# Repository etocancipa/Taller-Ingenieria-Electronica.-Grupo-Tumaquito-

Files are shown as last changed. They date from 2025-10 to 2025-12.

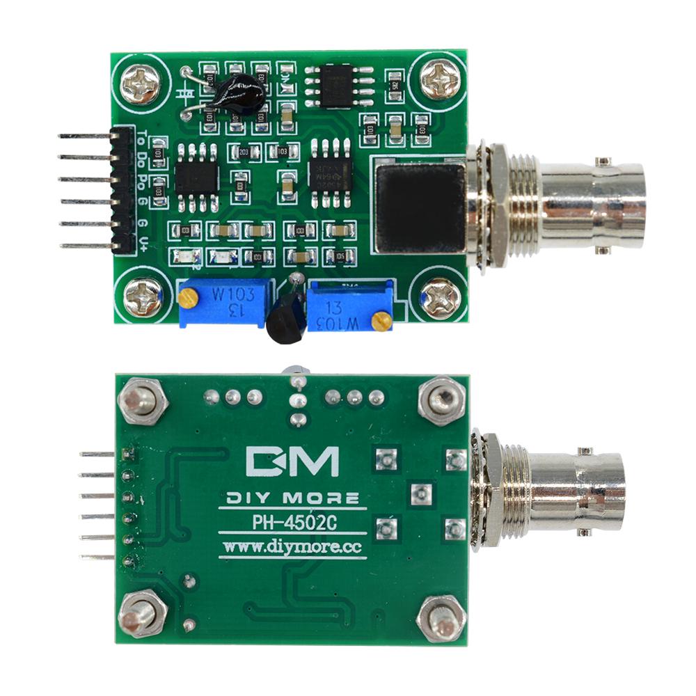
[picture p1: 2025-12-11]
PCB Tumaquito/Librerias/step/ph-4502c-1.snapshot.5/PH-4502C.jpeg

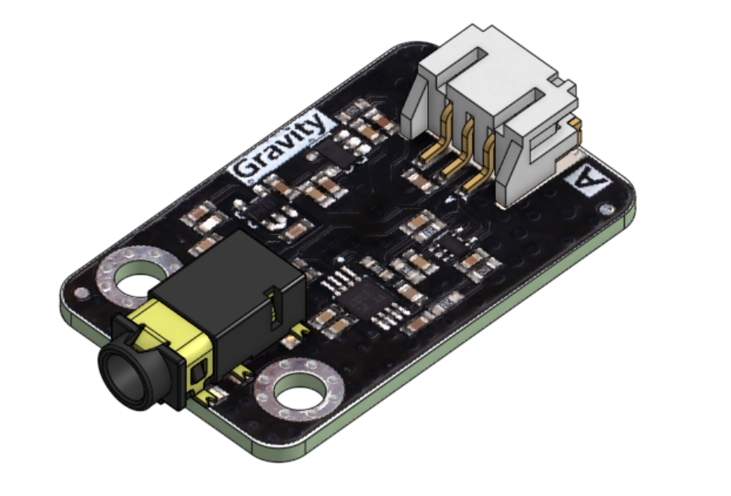
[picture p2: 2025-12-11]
PCB Tumaquito/Librerias/step/dfrobot-gravity-analog-emg-sensor-by-oymotion-sen0240-1.snapshot.2/emg_sensor.png

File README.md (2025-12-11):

# Taller-Ingenieria-Electronica.-Grupo-Tumaquito-
Este sera el repositorio del grupo "Tumaquito". Aqui se registraran la documentación y avances en el proyecto.

## LEER WIKI PARA DETALLES DEL PROYECTO

## Integrantes:
+Joseph Reyes

+Jose Dario

+Luis Cortes

+Eddy Tocancipa

+Helen Hernandez

+Sebastian Vanegas

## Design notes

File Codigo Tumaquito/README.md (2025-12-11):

# CODIGO APLICACIÓN Y ESP32:

El proyecto cuenta con una configuración para la ESP32 que pueda leer las señales analogicas.

Ademas de este codigo se cuenta con una aplicación hecha en APPINVENTOR, con su respectivo codigo en bloques.

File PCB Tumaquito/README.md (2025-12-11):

# ARCHIVOS PCB TUMAQUITO:

Aqui puedes encontrar la totalidad de los archivos que fueron utilizados para la creción de la PCB de Tumaquito!

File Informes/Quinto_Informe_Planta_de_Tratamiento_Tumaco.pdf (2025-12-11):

# Quinto Informe Planta de Tratamiento Tumaco

Luis Cortes
Helen Hernandez
Sebastian Vanegas
Eddy Tocancipa
Jose Dario
Joseph Reyes

Noviembre 2025

## 1. Introducción:

Durante esta quinta semana se arreglo la aplicación desarrollada para el proyecto, siendo ahora compatible con internet y funcional al conectarse con el servidor de la ESP32.
También se termino la PCB requerida para el proyecto, pero esta requerirá múltiples cambios recomendados por el profesor de Taller ademas de unos ajustes, se especificara en la sección del informe destinada a la PCB.
Se inició con el desarrollo de la caja del proyecto donde se instalaran los sensores, PCB y probeta requerida para las muestras.
El equipo tuvo un punto de flexión durante esta semana, esto se descubrió durante la exposición del miércoles y revoluciono nuestra perspectiva y forma de trabajo, se dedicara un apartado especial dentro del informe a nuestra nueva metodología de trabajo.

1

## 2. Aplicacíon Tumaquito:

La interfaz sigue siendo la misma, este es el ultimo punto a cambiar, lo que seria decorarla y añadirle estilo.
La aplicación en si es funcional, ya se conecta al servidor WIFI de la ESP32 y reconoce los valores analógicos que este manda. Se dejara este apartado en espera hasta que el dispositivo este armado, se harán las pruebas en aquel momento.

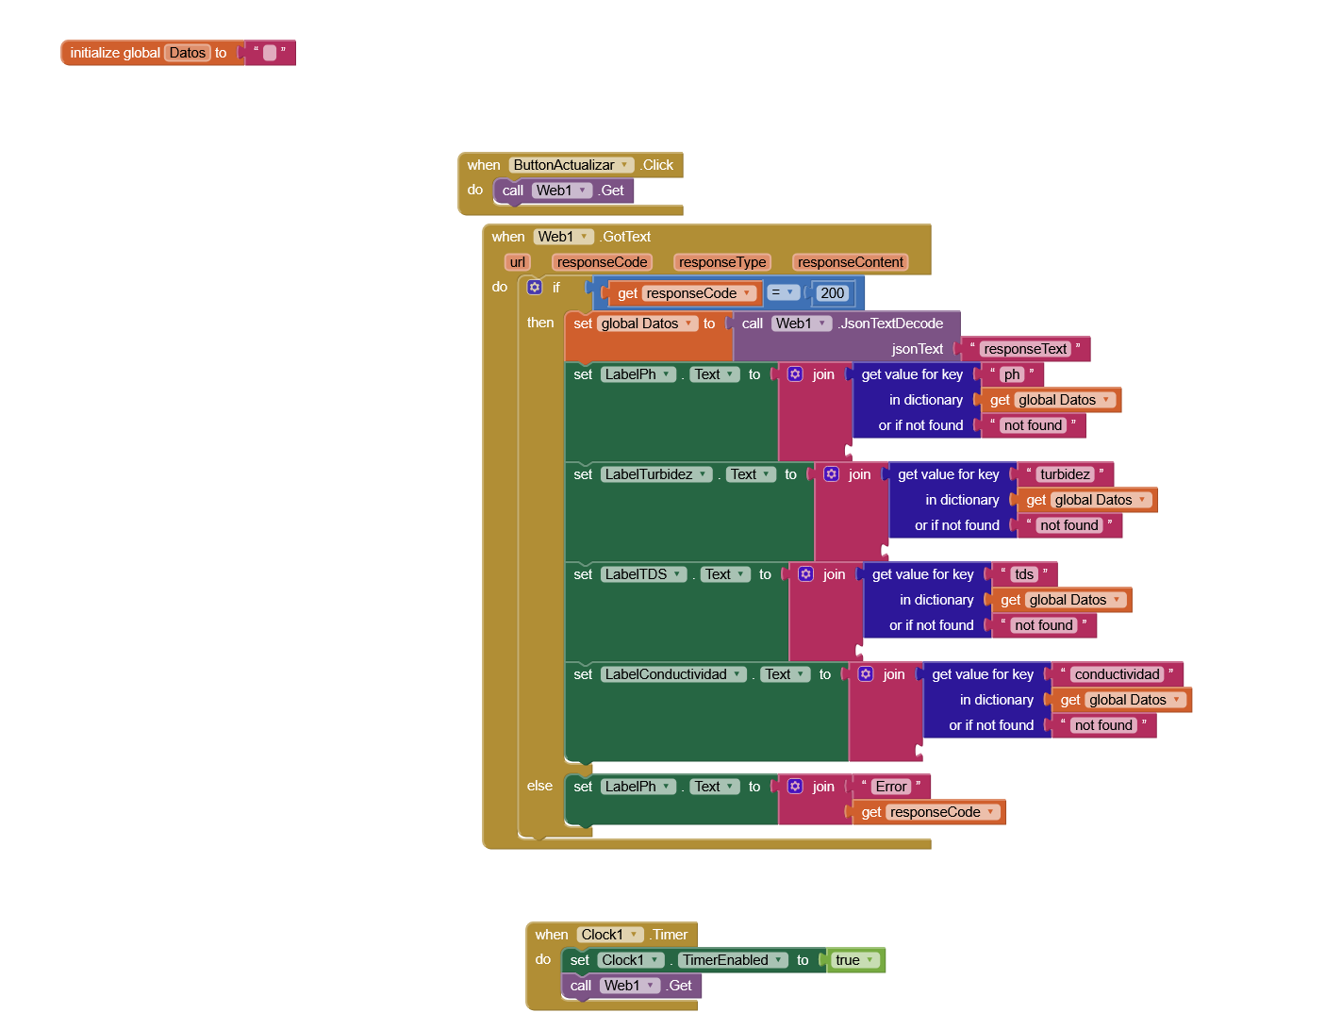
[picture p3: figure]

Figura 1: Nuevo codigo adaptado al servidor WIFI de la ESP32

## 3. Programación servidor ESP32:

Nos encontramos con un problema al configurar el código de los 3 sensores y subirlo al servidor ya que los valores enviados superan una capacidad máxima dada por el ESP32. Esto al probar el servidor con los sensores por separado no sucedía por la menor cantidad de datos que se recibían. Nos pusimos en contacto con unos estudiantes de programación que apoyan en Tutorías con Ingenio para saber si nos ayudaban a solucionar este problema o reconocer como tratarlo.

2

## 4. PCB:

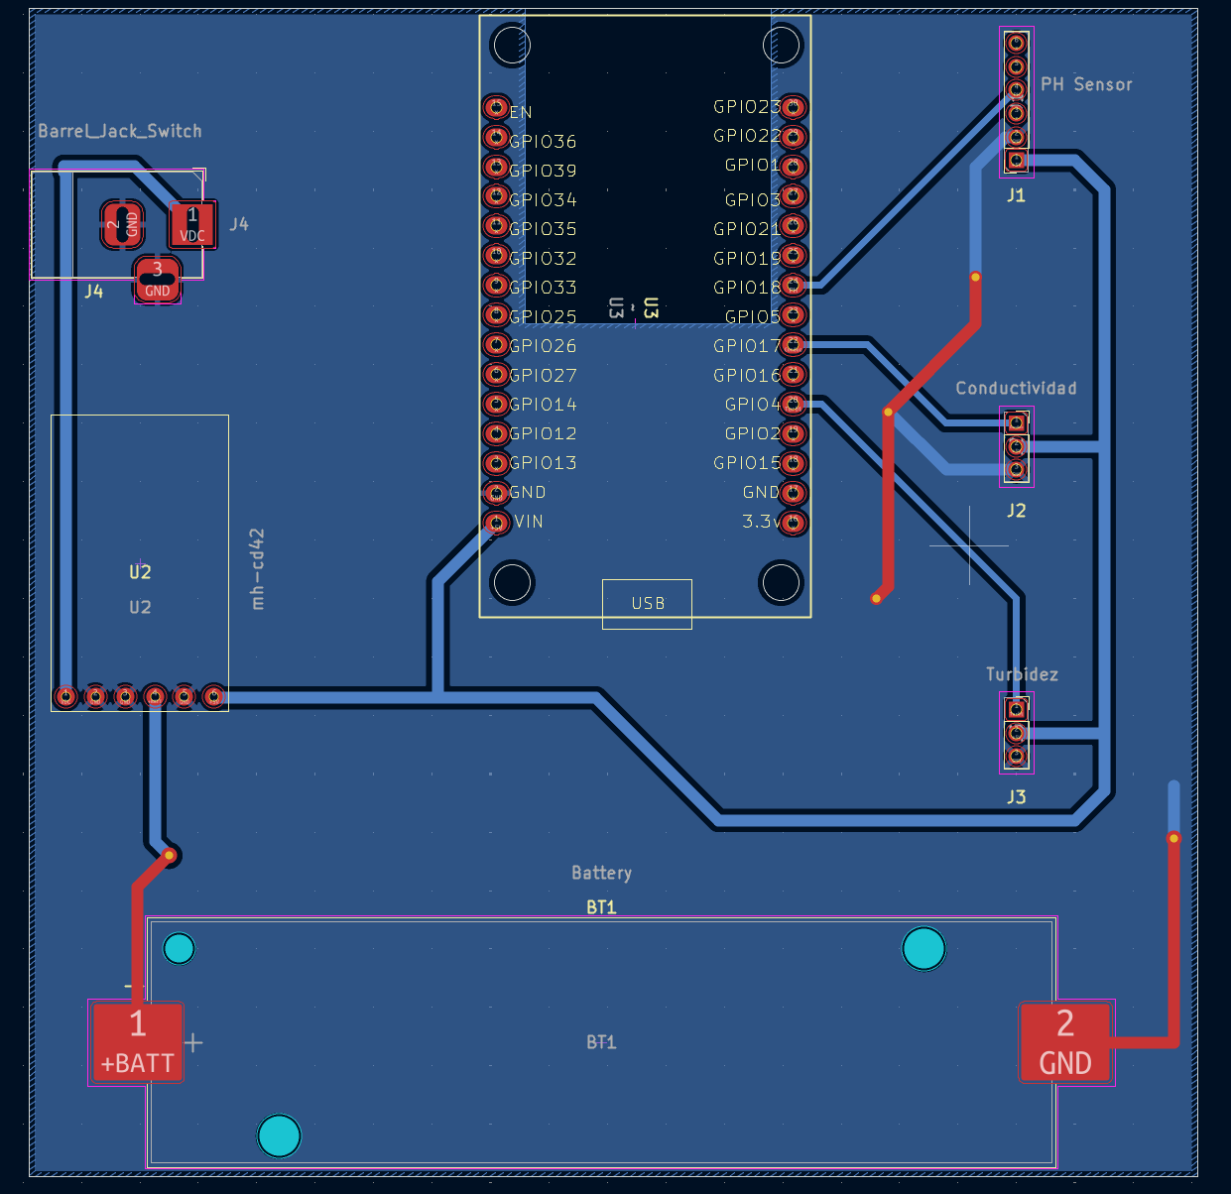
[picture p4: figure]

Figura 2: Version 1.

La imagen de arriba presenta la PCB que fue presentada al profesor de Taller, este hizo numerosos apuntes que se enumeraran a continuación:

### 1. Los sensores (Conectores de la derecha) Deben ser movidos a la izquierda

de la PCB para utilizar los Pines del bloque 1, ya que los pines a los que se conectaron tienen interferencias al usar el modulo WIFI de la ESP32.

### 2. Los sensores de conductividad y turbidez deben ser movidos a la entrada de

energía 3.3V ya que aunque funcionan en la entrada VIN se genera un campo eléctrico que puede causar interferencias entre ellos.

### 3. Este cambio fue descubierto por nosotros al probar el sensor de PH en el

ESP32 en vez del arduino, y es que este al dar señales analógicas de 5v no son captadas por el ESP32, se le comento al profesor de taller y nos dijo que implementáramos un divisor de voltaje en la PCB con un potenciómetro para bajar la señal de 5v a 3.3v o 3v.

### 4 Hubo ajustes pequeños como el tamaño de las vías o el margen que tienen

estas con la base GND.
Ya estamos realizando estos cambios necesarios para poder enviar a imprimir la PCB, se comunicara con el profesor de Taller de forma virtual para avisar si los cambios hechos fueron realizados de manera correcta.

3

## 5. Caja del Proyecto:

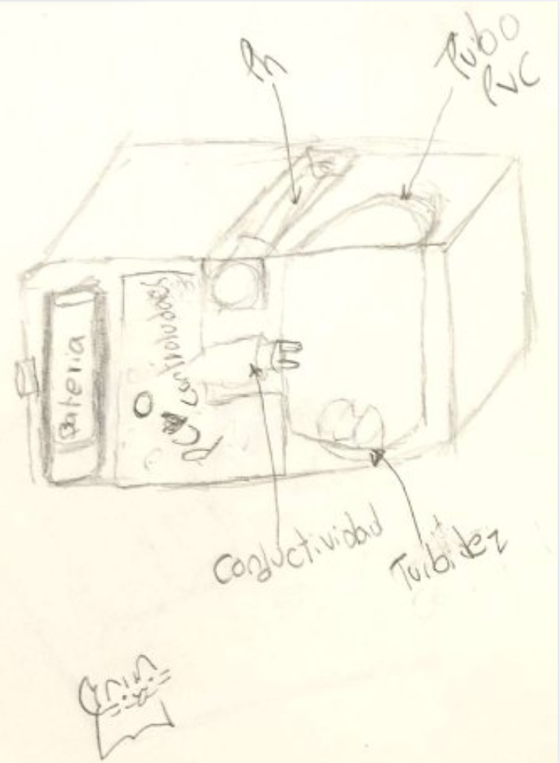
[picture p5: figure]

Figura 3: Bosquejo Caja del proyecto.

Seguimos en un bosquejo (Se programo reunir el viernes para definir al completo la caja).
Tenemos conceptos claros como el tubo de PBC dividido para cada sensor, el sistema de energía utilizando un jack y la forma en general que tomara la caja ”Tumaquito”. Se piensan definir materiales, dimensiones y cronograma para ensamblaje y pruebas.

## 6. Nueva metodología:

Hasta el momento el equipo había cumplido con las tareas asignadas a cada integrante, cada uno trabajo como lo esperado y se realizaban pequeñas reuniones para acordar actividades o cuadrar exposiciones.
Aun así fuimos expuestos a un problema durante la ultima exposición que nos dio a conocer nuestra mayor inconveniente y es que en realidad estábamos trabajando de forma individual, de forma que cada uno tenia una idea general pero distorsionada del proyecto, se generaban contradicciones y confusiones en ciertas áreas de trabajo.
Este individualismo se genero por una falta de presencia en el trabajo grupal, cada uno tenia su propia actividad y no se preocupaban por la de otro o por una perspectiva mas ”General”. No se acordaba una actividad que se desarrollara

4

con el grupo entero de forma presencial.
Tuvimos esta conclusión y nos dimos cuenta que no dábamos la imagen de ’Equipo’. Para contrarrestarlo decidimos desarrollar el resto del proyecto de forma presencial, de manera continua y casi diaria evitando en la medida de lo posible destinar tareas y procesos de forma individual.
NOTA EDDY: Cada uno estuvo de acuerdo y de hecho fueron 4 integrantes los que propusieron esta metodología, nos pusimos de acuerdo en que íbamos a trabajar de manera presencial y dedicarle nuestro tiempo y espacio a el apartado de ensamblaje y construcción de lo que queda del proyecto.

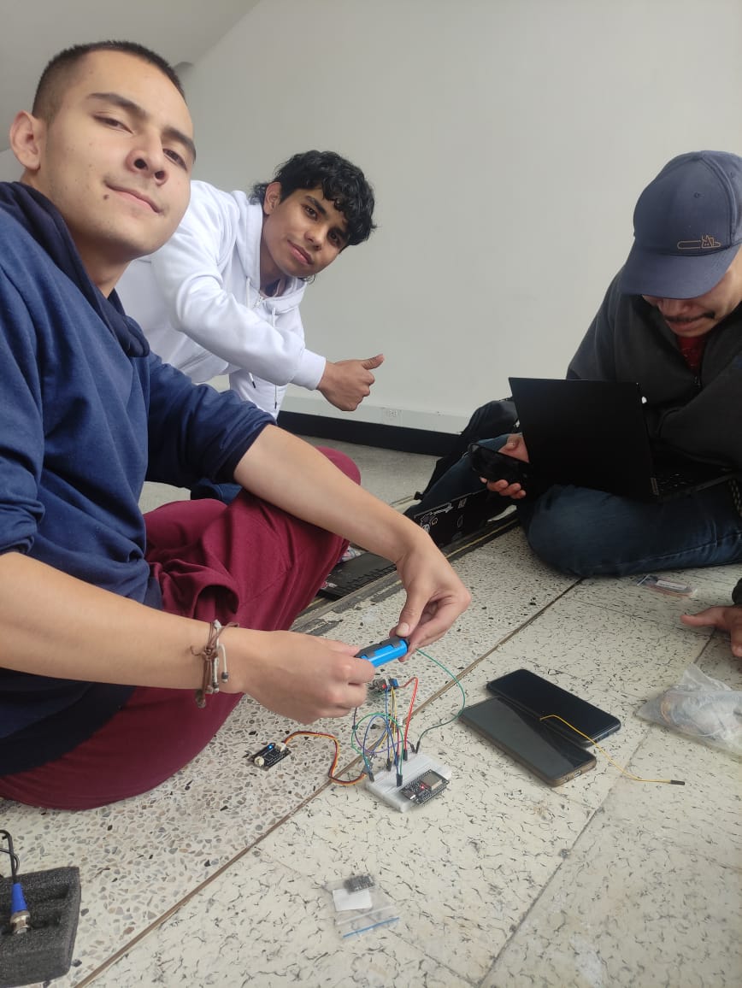
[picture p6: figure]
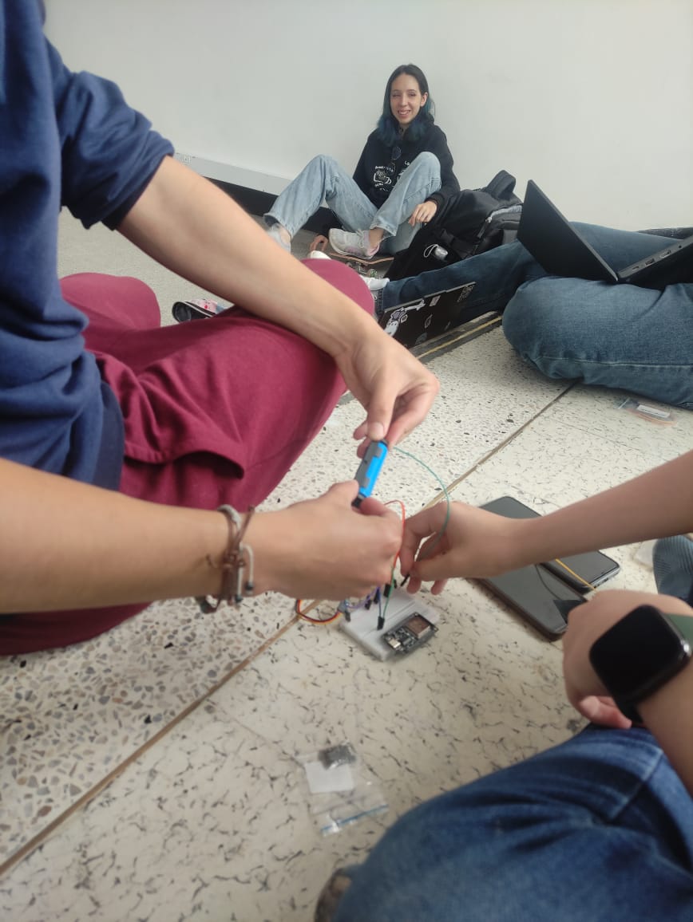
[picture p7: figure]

5

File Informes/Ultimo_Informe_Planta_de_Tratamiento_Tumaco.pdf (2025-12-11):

# Ultimo Informe Planta de Tratamiento Tumaco

Luis Cortes
Helen Hernandez
Sebastian Vanegas
Eddy Tocancipa
Jose Dario
Joseph Reyes

Diciembre 2025

## 1. Introducción

Estas ultimas 2 semanas hemos trabajado en todo el aspecto técnico y cacharrero.
Trajimos a la vida ”Tumaquito”. Logramos imprimir la PCB, Soldar los componentes y tener parte la caja lista. En términos generales solo quedaría montarlo todo en un solo dispositivo y solucionar varios errores que hemos tenido. Iremos paso a paso.

## 2. PCB

Tuvimos el visto bueno del profesor de taller. Este vio nuestro diseño, nos aconsejo unos cambios menores y después de arreglarlos la mandamos a imprimir.
Una vez imprimida notamos solo 2 temas, los agujeros para el jack eran muy chiquitos y no cabía por completo el porta-pilas, afortunadamente estos problemas se solucionan de forma sencilla reduciendo el tamaño de los pines del jack y un poco de ayuda para soldar el porta-pilas, esto para que tenga el roce necesario con el cobre.

1

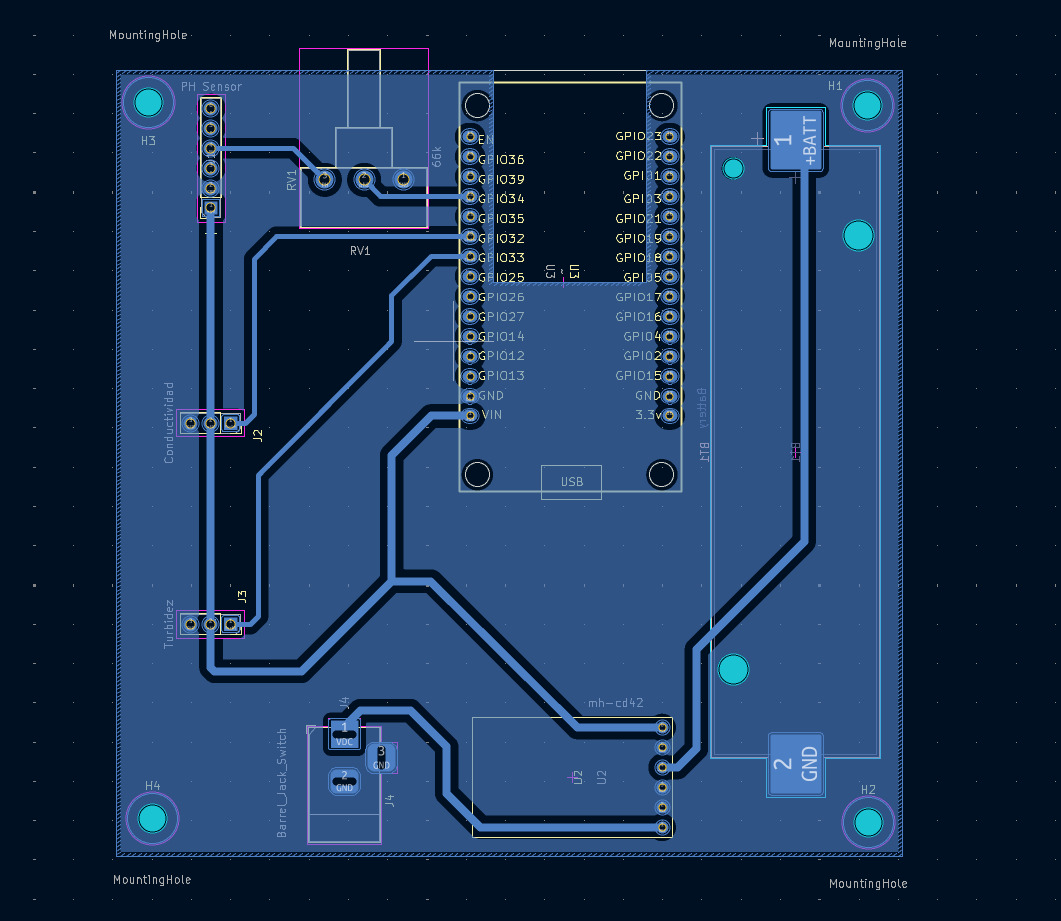
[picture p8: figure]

Figura 1: Diseño final de PCB

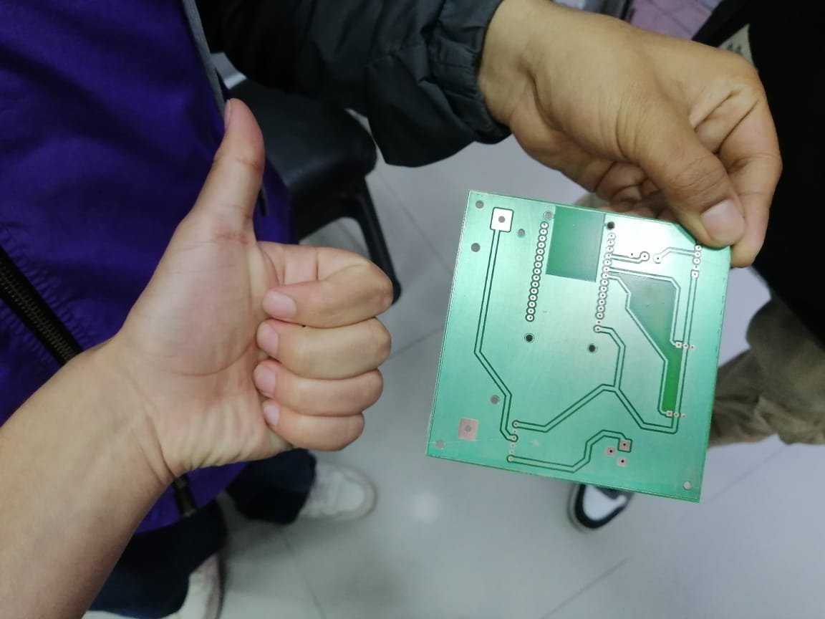
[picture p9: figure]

Figura 2: Recogiendo la PCB

2

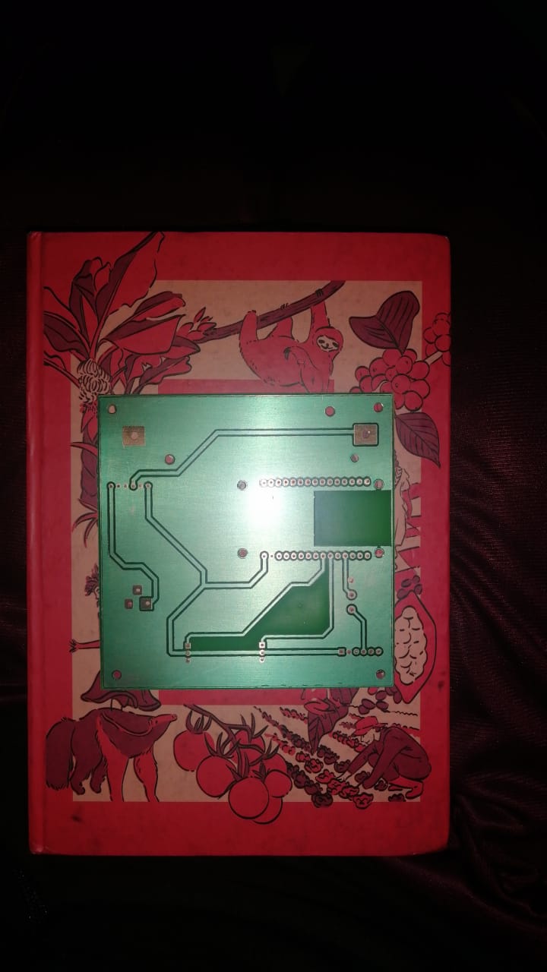
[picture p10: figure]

Figura 3: PCB por detrás. Circuito.

3

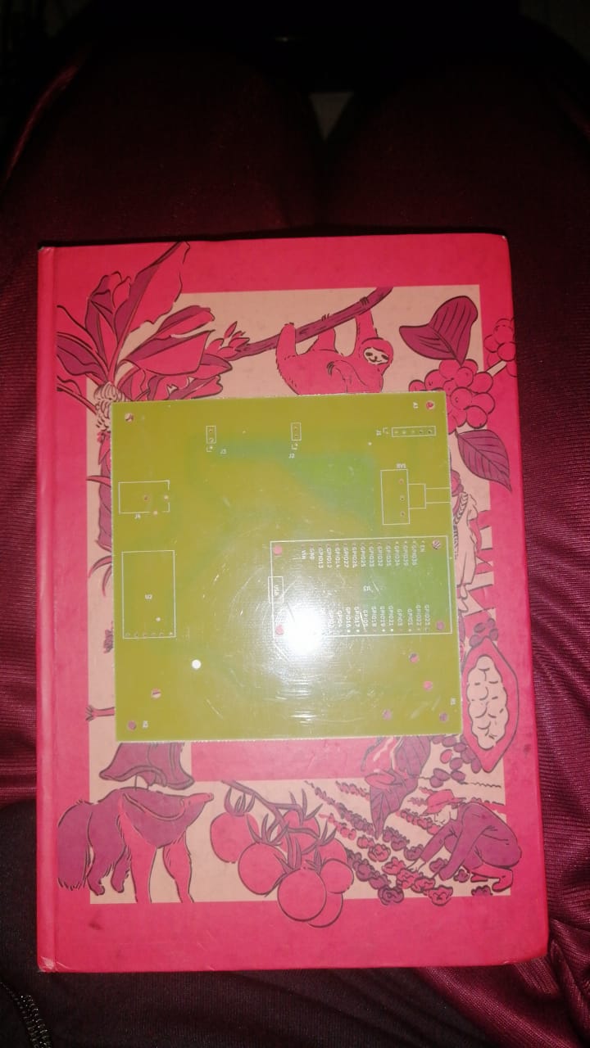
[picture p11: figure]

Figura 4: PCB por delante. Componentes.

## 3. Soldadura

Era nuestra primera vez para la mayoría del equipo, por lo que al momento de soldar tuvimos varias dificultades.
Cada uno quería practicar y mejorar su soldadura por lo que nos dividimos los componentes, Soldamos por 3 días turnándonos la PCB y revisando continuamente que nos fuera quedando de manera adecuada.
No fuimos muy limpios con el cautín por lo que al final su punta se lleno de corrosión y dejo de calentar como es debido.
Utilizamos flux demás, esto causo que la PCB Queda pegachenta al tener un montón de liquido derramado, tardamos un tiempo en limpiarla porque teníamos miedo del alcohol normal y que dañara la PCB.
Varios metimos mas estaño del que debíamos, quedando con pines muy robustos, a fecha de la escritura de este informe tenemos problemas con la conductividad de energía de algunos componentes, quizá por mala soldadura.

4

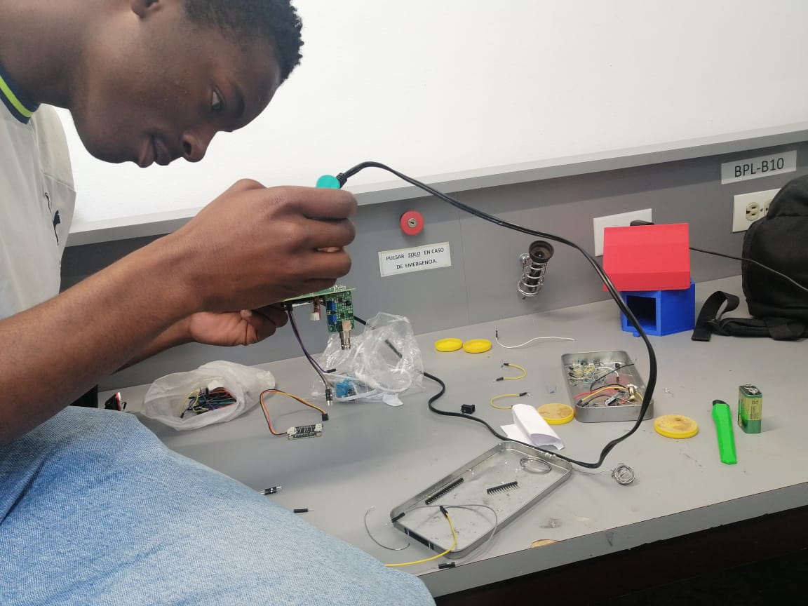
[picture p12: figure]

Figura 5: Soldando

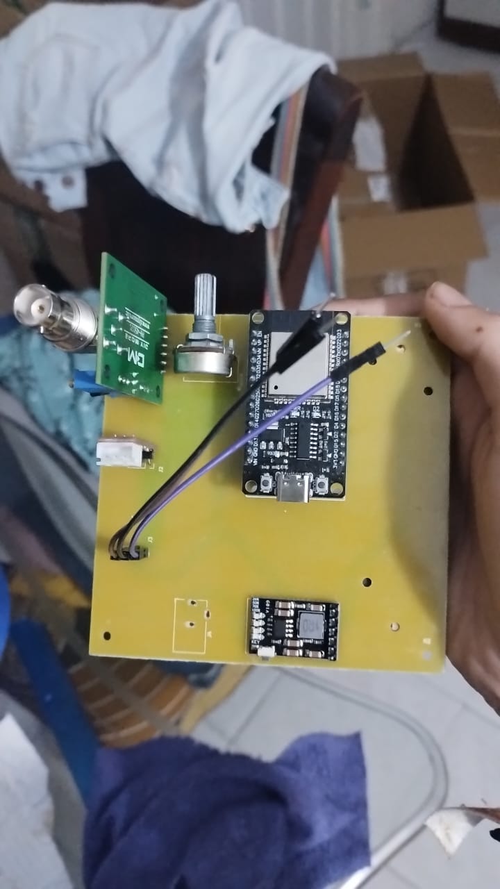
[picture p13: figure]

Figura 6: Soldadura Delantera PCB

5

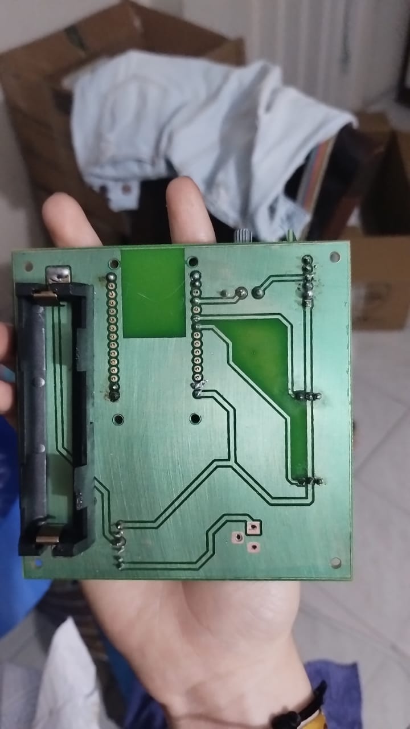
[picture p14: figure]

Figura 7: Soldadura Trasera PCB

## 4. Caja Tumaquito

Con las mediciones de la PCB, un tubo de muestra y el espacio a ocupar por los sensores, pudimos adelantar un diseño hecho en tinkercard que después imprimimos a 3D, dándonos nuestro primer esquema de caja y donde planeamos instalar todos los componentes.
Al principio pensamos en una caja, pero después de varias charlas dijimos que era muy feo. Optamos por un un cilindro.

6

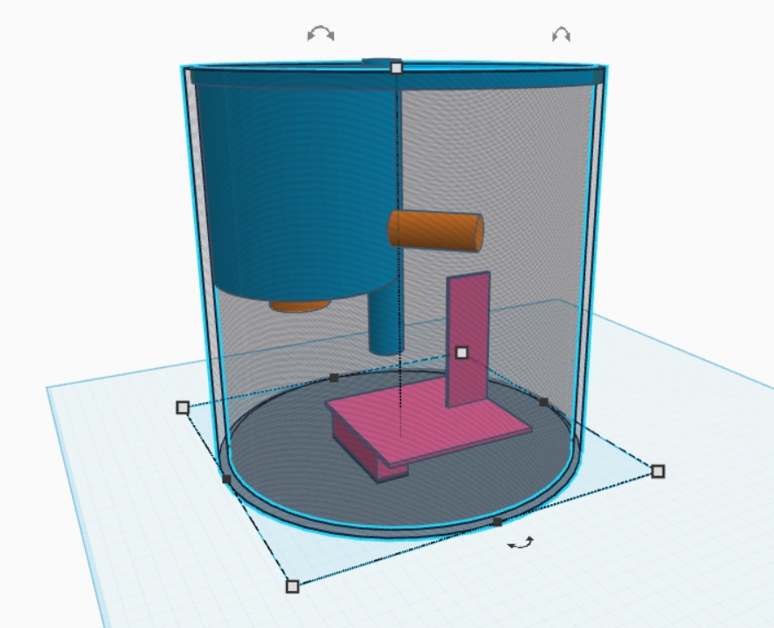
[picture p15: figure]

Figura 8: Boceto Caja tinkercard

Después de este boceto nos enteramos que la sonda de PH seria un problema para el proceso de mantenimiento por lo que decidimos que esta se pueda sacar de la caja e interactuar de manera manual por el usuario para medir la muestra.

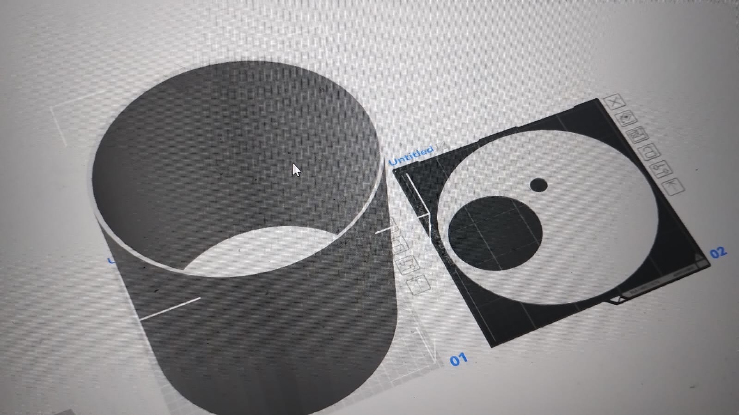
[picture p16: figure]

Figura 9: Diseño Final Caja

Ya con este diseño se empezó la impresión 3D.

7

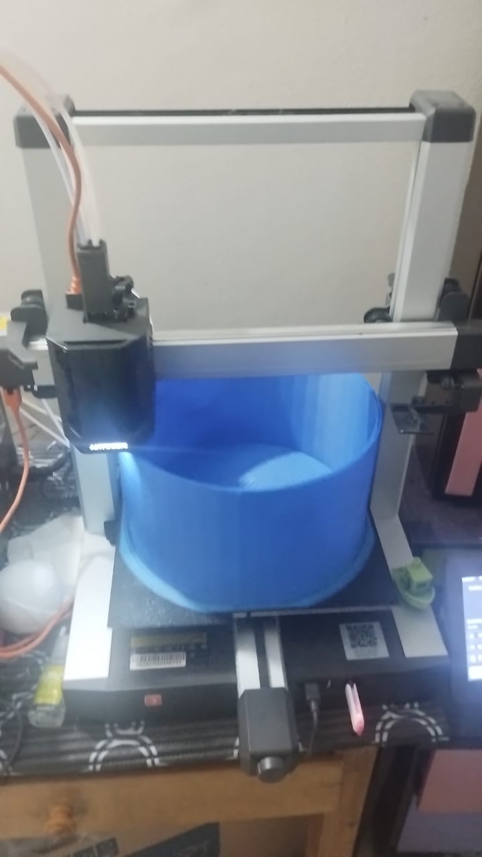
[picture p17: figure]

Figura 10: Impresión Caja 3D

En ultimas los problemas al montar todo en la caja vendrán durante estos últimos días de trabajo ya que es la parte final para poder entregar a Tumaquito. Se tiene el espacio para cada componente, lo necesario sera realizar los huecos tanto para el jack como para la calibración del sensor de PH.

## 5. Aplicación

La aplicación se encuentra funcional. Varios miembros dedicaron tiempo en mejorar su interfaz y añadir funciones.
Ahora la aplicación puede dar un ”Tratamiento”que busque (según el estado del agua y sus parámetros medidos) aconsejar al usuario en un método de acción que ayude a purificar el agua, haciendo posible su uso.
Aun faltan pruebas con soluciones y muestras para saber si esta nueva función se encuentra en buen estado, pero debido a problemas con la conductividad en la PCB se han aplazado estas pruebas.

8

## 6. Problemas:

### 1. Dañamos la sonda de PH. Esto por conectarla directa sin bajar el voltaje de

su pin analógico. Dimos vueltas por la 19 buscando que nos vendan unicamente la sonda pero no tuvimos suerte, al final la ordenamos por internet.

### 2. Hay un ’salto’ en la lectura de datos de los sensores debido a que todos están

al mismo pin de la ESP32, este margen de error se puede manejar por medio de programación.

### 3. No sabemos bien, de pronto por soldar mal o por realizar pruebas con pines en

corto, pero algunos componentes como el controlador de turbidez y el cargador de baterías cd-42 no conducen la energía la PCB lo que genera que no se lean sus datos o que por medio de una pila no se pueda encender todo el circuito. Esperamos obtener ayuda por parte de los profesores de taller en caso de que nuestros esfuerzos por solucionar estos problemas se vean en vano.

## 7. Terminación

Nuestros últimos pasos para el proyecto serian solucionar el tema de la PCB para que funcione y los sensores lean los datos alimentados por una pila, ademas de instalar todos los componentes en la caja y decorarla. Muchas gracias.

FIN DEL INFORME

9

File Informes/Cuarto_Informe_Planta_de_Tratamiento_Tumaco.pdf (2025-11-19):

# Cuarto Informe Planta de Tratamiento Tumaco

Luis Cortes
Helen Hernandez
Sebastian Vanegas
Eddy Tocancipa
Jose Dario
Joseph Reyes

Noviembre 2025

## 1. Introducción

Esta cuarta semana se trabajo en el circuito de los componentes del proyecto, así terminando una versión pendiente de la revisión del profesor de taller y que a la vez pueda trabajarse en la creación de la PCB, la cual sera objetivo para la 5° semana.

Se trabajo con el APPINVENTOR, obteniendo una beta de la aplicación para celular que se usara en la sincronización de datos con la ESP32. Se mostraran componentes de la interfaz que reflejan como se verán los datos en pantalla recibidos de las muestra.

Aparte de estos 2 avances se hicieron mas pruebas con los sensores, realizando cambios en su programación, ajustes y adaptando el informe que el usuario use dentro de la aplicación.

1

## 2. Circuito Electrónico - Componentes

Utilizando Kicad, se siguió el tutorial hecho por el profesor Johnny Cubides que enseña lo básico para desenvolverse en la plataforma. Se idearon las conexiones, tierras y sistema de energía que alimente a los sensores.
Este es el esquema:

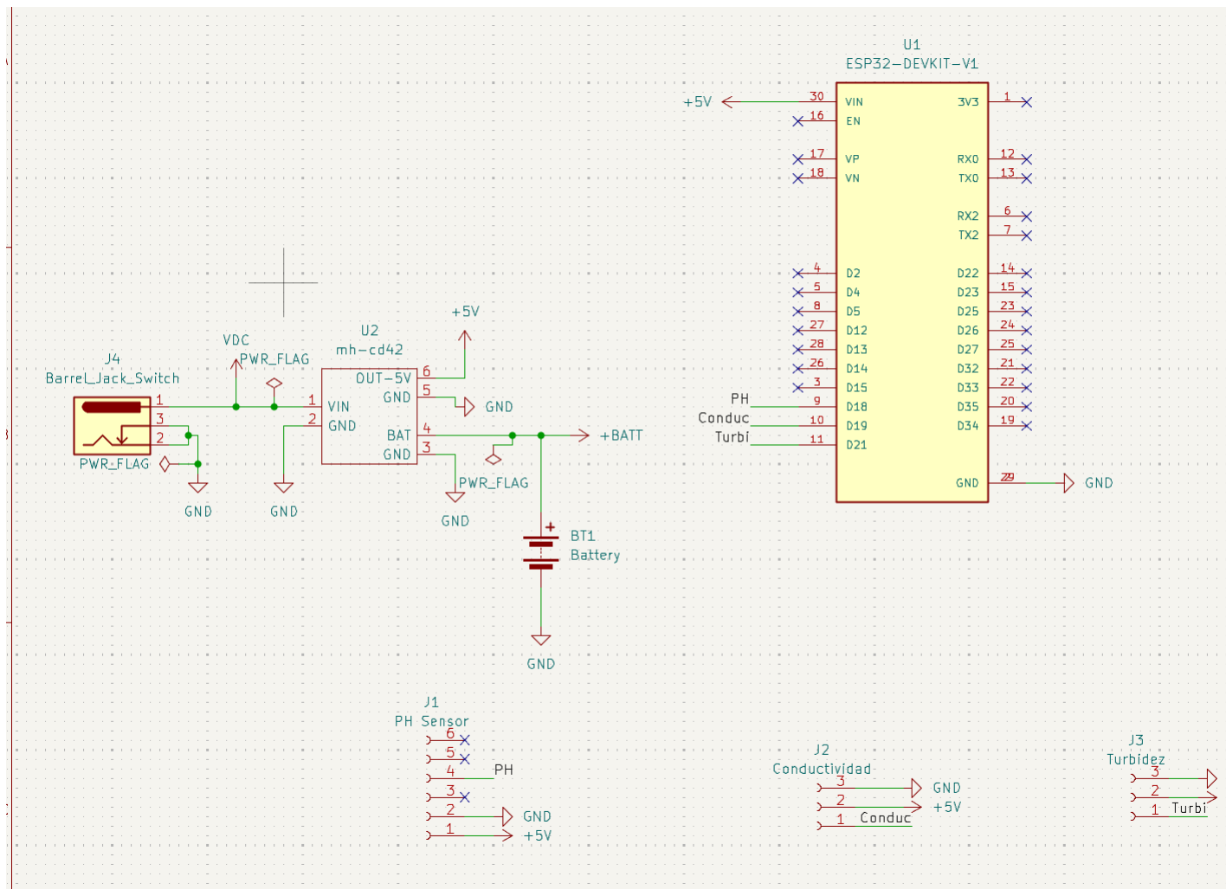
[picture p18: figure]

Figura 1: Circuito ideado en KICAD

Como resumen, los 3 componentes de la izquierda son la energía del sistema (Jack, Batería, Cargador de batería).
Los 3 componentes de abajo de la imagen son los sensores representados unicamente con sus conexiones (Hembra) Debido a que no existen símbolos y huellas de ellos para este programa.
El componente de la derecha - arriba es la ESP32 que, usando un diagrama de conexión del fabricador de donde conseguimos nuestra ESP32, nos pudimos

2

guiar en los pines a usar que facilitaran su acomodación durante la creación de la PCB.

## 3. Aplicación TUMAQUITO:

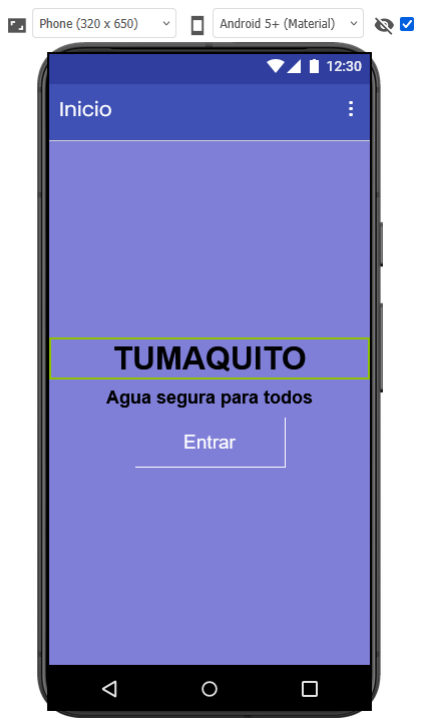
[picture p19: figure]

Figura 2: Pantalla 1

Figura 3: Programación Pantalla 1

3

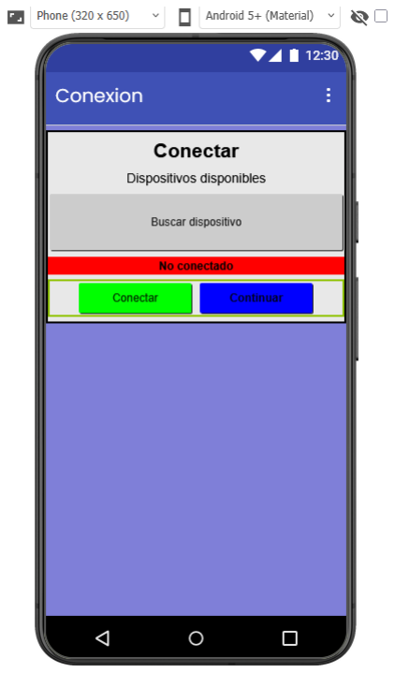
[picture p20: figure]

Figura 4: Pantalla 2

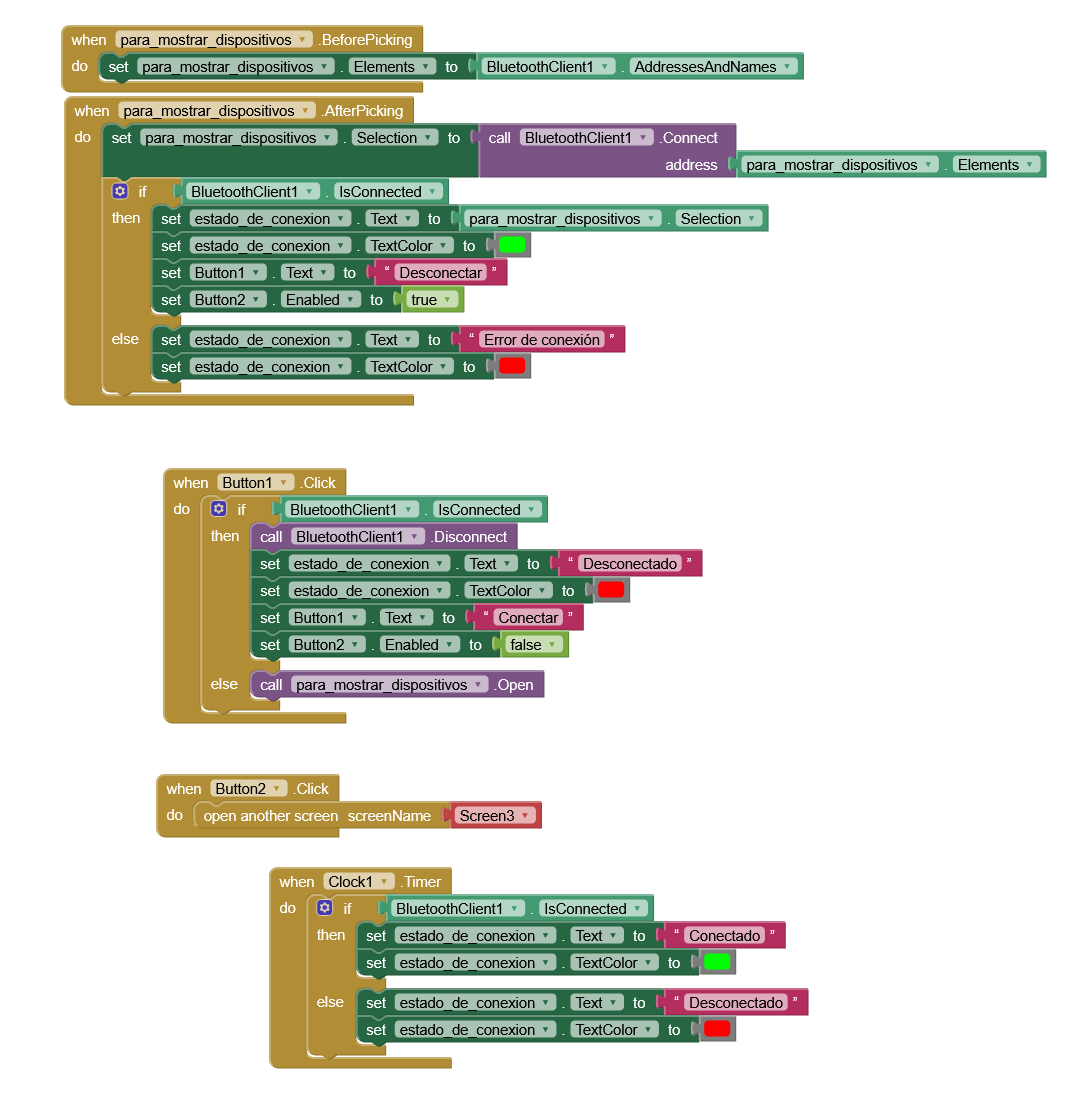
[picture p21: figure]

Figura 5: Programación Pantalla 2

4

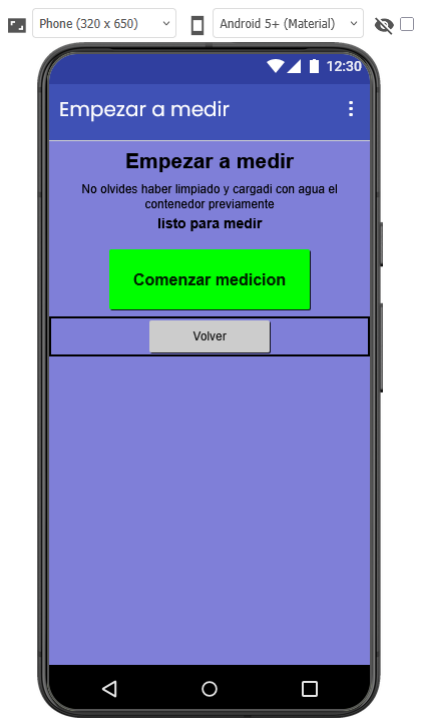
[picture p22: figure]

Figura 6: Pantalla 3

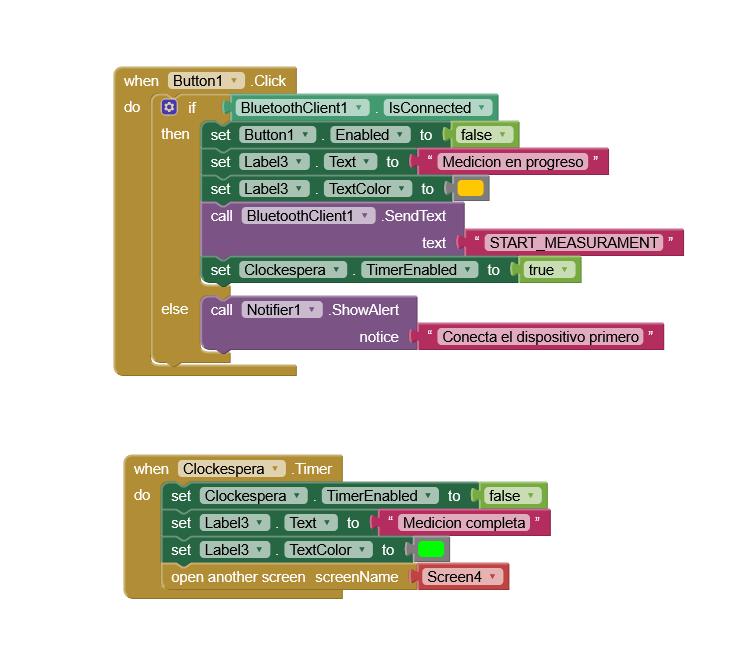
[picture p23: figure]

Figura 7: Programación Pantalla 3

5

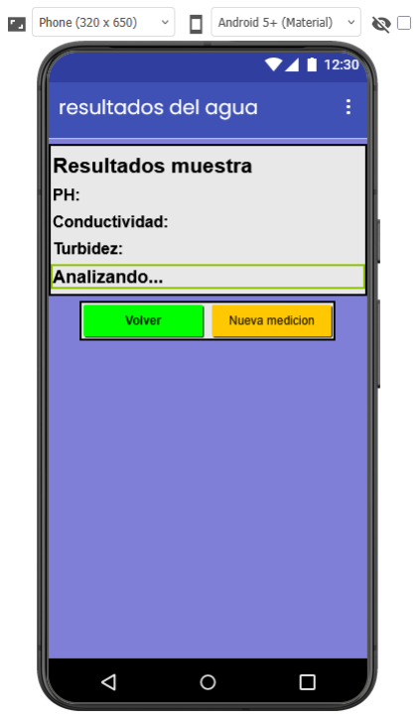
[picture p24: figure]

Figura 8: Pantalla 4

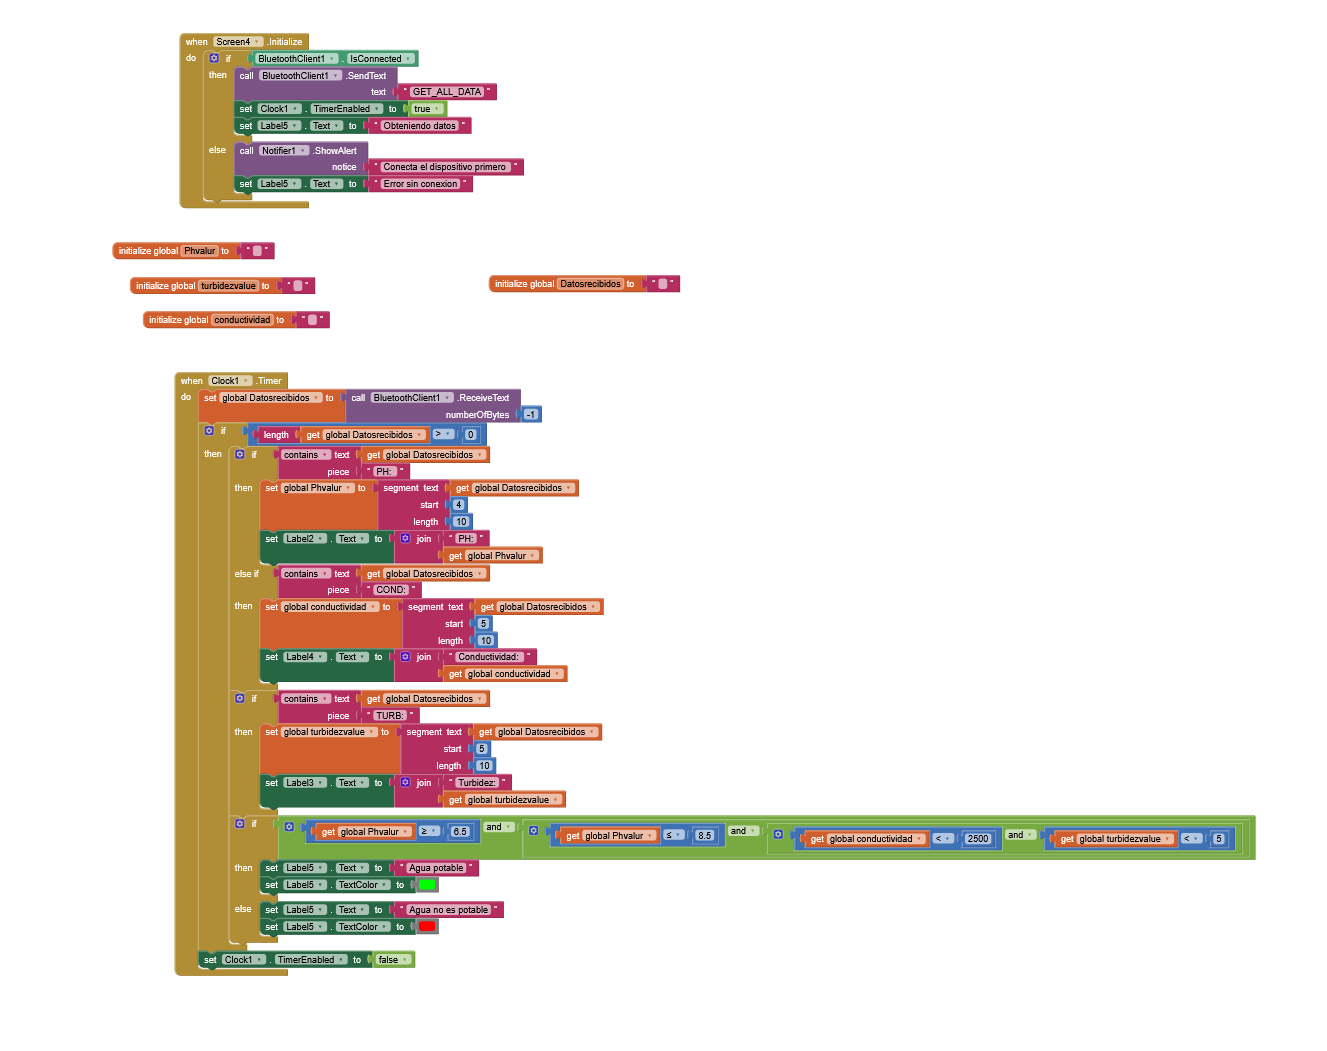
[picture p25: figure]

Figura 9: Programación Pantalla 4

Esta NO es la versión final. Es una ”Beta”funcional que da una idea de adonde se va dirigiendo la aplicación.
Debido a un problema de comunicación se configuro la aplicación con Bluetooth en vez de internet como era planeado. Las mejoras y cambios que se buscan es una mejor decoración para la interfaz y adaptar la programación para Internet en vez de Bluetooth.

6

## 4. Actividades Varias:

Se volvieron a seguir los procedimientos de calibración de los sensores de turbidez y conductividad ya que la primera vez se realizaron con ARDUINO y por lo tanto al cambiar el código a un ESP32 tuvieron desfases en las mediciones.

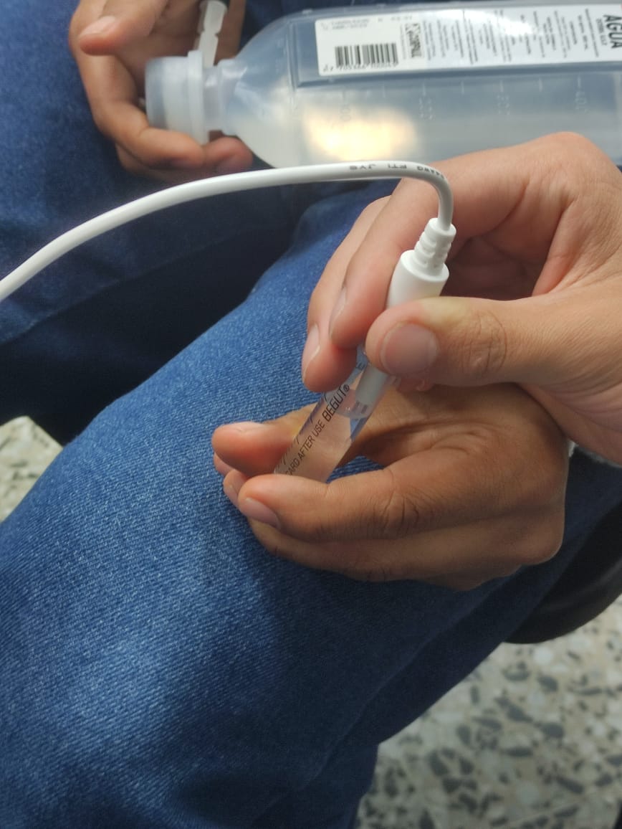
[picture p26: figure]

Figura 10: Calibración

## 5. Actividades Futuras:

Se tendrá como prioridad el desarrollo del case y de la PCB ya que estamos a las ultimas semanas para culminar el proceso de traer el proyecto al mundo físico. Se busca que tanto el circuito electrónico como la PCB se presenten al profesor de Taller para el siguiente miércoles y que les de el punto de vista bueno o en caso necesario correcciones. También 2 miembros del equipo se dedicaran al diseño de la Caja donde se instalaran la PCB y Sensores.

FIN DEL INFORME

7

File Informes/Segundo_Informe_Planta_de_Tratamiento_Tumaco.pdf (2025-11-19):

# Segundo Informe Planta de Tratamiento Tumaco

Luis Cortes
Helen Hernandez
Sebastian Vanegas
Eddy Tocancipa
Jose Dario
Joseph Reyes

November 2025

## 1. Introducción

Antes de comenzar se dará aviso de un cambio realizado en el proyecto: El equipo acordó cambiar el enfoque y estructura del proyecto, en esencia simplificándolo y ajustándolo a una visión posible para nuestras capacidades y conocimientos actuales. Se dará un resumen de los cambios y se abordaran en profundidad mas adelante.

### 1.1. Cambios:

1. El robot a fabricar no trabajara en un ambiente de tuberías.

### 2. No sera un robot estacionario. En cambio, sera un ”Medidor de calidad de

agua”portable.
3. No se usaran sensores de presión.

## 2. Nuevo Proyecto

Se fabricara un robot que mida 3 parámetros del agua: 1. PH 2. Turbidez (SST) 3. Conductividad (TDS)
Este robot sera una Ç aja”Que contenga un contenedor para la muestra de agua a medir, los 3 sensores antes mencionados y una transmisión de datos por medio de IoT hacia una aplicación diseñada para mostrar los parámetros medidos e información acerca de estos.
El objetivo de este robot sigue siendo el de proporcionar una herramienta de medición que permita conocer la calidad de agua. El uso de este ha sido extendido a un publico mayor y no solo al uso del personal de planta de agua.

1

### 2.1. Objetivos especificos

-Recolectar datos en tiempo real
-Prevención de riesgos sanitarios
-Apoyo en la sostenibilidad ambiental
-Difundir conciencia y conocimiento frente al estado del agua
2.2. ¿Porque se cambio de proyecto?

Palabras mas, palabras menos, nos quedo grande. No conocíamos la forma de trabajar señales bajo el agua, tampoco el profesor de taller. Los materiales a usar podrían suponer un riesgo de desgaste lo cual contaminaría el agua en el punto de instalación, ademas de que los materiales del chasis que se requerían salían del presupuesto.
La propia instalación del robot fue uno de los mayores retos, no poseíamos el ambiente de prueba necesario para saber acoplar el robot a la tubería y que soporte un flujo de agua, esto acompañado de una discordancia en horarios que limitaba nuestra capacidad de practicas con el grupo completo.
Aprendiendo mas sobre los sensores nos enteramos que la calibración de estos debía ser periódica y manual, lo que resultaría poco practica y bastante incomoda de trabajar si el robot se .Estacionara”durante largos periodos en la tubería. En conclusión decidimos simplificar el proyecto para no afrontar una gran cantidad de retos que dedicaban mucho mas tiempo y conocimientos de los que disponíamos.

## 3. Avances segunda semana

Se busco durante la segunda semana concretar el uso de sensores y conocimiento frente a estos (Como operan, parámetros, calibraciones, instalación, costos). Ademas de trabajar con sensores y gracias al nuevo enfoque pudimos aclarar mejor el diseño de nuestro robot. Consiguiendo un diagrama de flujo, caja negra y tecnológico que encapsula el futuro y planeamiento del proyecto de forma concisa.

### 3.1. Sensores:

Aun no se han comprado los sensores debido a que se esta esperando la perspectiva y recomendaciones del profesor de taller.

2

### 3.1.1. PH

Se usara el siguiente sensor: Dame click! (https://ja-bots.com/producto/sensor-ph-liquido/)


Figura 1: Sensor PH

Costo: 100k - 150K. Este sensor cuenta con una sonda la cual requiere estar dentro de una solución de almacenamiento de un PH Neutro.
Posee también un controlador el cual contiene un potenciómetro el cual es necesario ajustar para calibrar el sensor.
Trabaja a 5v (Como adelanto, se trabajara con un ESP32) Por lo que se requerirá un divisor de voltaje en el circuito para lograr que se adapte al micro-controlador.
Calibración - Mantenimiento: Se recomienda una calibración cada 3 días o si se han realizado múltiples medidas, el mismo día. Para esta calibración se requieren de soluciones o buffer con PH ya conocido, se miden 2 puntos con PH 4.01 y PH 10.1. Para mantenimiento se recomienda después de cada uso enjuagar la sonda con agua destilada.
NOTA!: El sensor es bastante delicado, el uso de agua destilada debe ser aplicado con precaución. (Esta caro el sensor :c )

3

### 3.1.2. Turbidez (SST)

Se usara el siguiente sensor: Dame click! (https://www.mactronica.com.co/sensor-de-turvidez-de-agua)


Figura 2: Sensor Turbidez

Costo 40k - 50k. En si trae el sensor y el controlador. Trabaja a 5v igual que el de PH por lo que un divisor de voltaje sera necesario. Funciona a través de un espectro de luz que detecta las sombras (Solidos) suspendidos en el agua (SIMPLIFICACION). Por lo que es recomendable trabajarlo en ambientes de ´ poca luz.
Calibración - Mantenimiento: Su calibración se hace por medio de programación ya que el controlador no posee potenciómetro para girar. Se hacen 2 puntos, 1 con agua destilada (0 Solidos) y otro con una solución (NTU) Ya conocida, así se mapean ambos puntos junto a la calibración. Se recomienda calibrar cada semana y en cuestión a su mantenimiento: Después de cada medición enjuagar con agua destilada.

4

### 3.1.3. Conductividad (TDS)

Se usara el siguiente sensor: Dame click! (https://www.mactronica.com.co/sensor-de-conductividad-del-agua)


Figura 3: Sensor Conductividad

Costo 50k. Trae la sonda y el controlador. Trabaja a 3.3V por lo que es compatible con el ESP32
Calibración - Mantenimiento: También se calibra por medio de programación, se puede usar solo 1 punto de medición y se usa un buffer o solución con valor de cm/S (Siemens) conocidos, por ejemplo una solución de KCL. Se están buscando formas caseras para crear esta solución porque están CARISIMAS y es como un tarro chiquito pa pintar las uñas. Se hablara con el profe de taller acerca de esto.
El mantenimiento es cuestión de enjuagarlo con agua destilada después de cada medición y su calibración cada semana.

### 3.2. Contenedor

Se buscara imprimir una probeta con PVC en impresora 3D. Esta debe ser una probeta divida en 3 segmentos (Cada segmento por sensor) Debido a que el sensor de conductividad y PH trabajan con pequeños Iones que, si llegan a estar en contacto con la misma muestra pueden variar los parámetros que midan. Por esta razón la probeta a diseñar va a estar dividida, con proporción al tamaño de los sensores y de plástico para que sea resistente y fácil de lavar.
Es recomendable lavar la probeta con agua destilada después de cada medición.

### 3.3. Micro-controlador y Aplicación

Debido a que el ESP32 tiene un modulo de WIFI lo que facilita la implementación de la herramienta IoT (Internet de las cosas), se podrá utilizar este para mandar sus datos a una aplicación que los reciba, esta aplicación no solo mostraran los parámetros de la muestra si no que también poseerá una guía en

5

la calibración y mantenimiento del robot así como un informe que explique a detalle que significan los parámetros medidos y si en conclusión la calidad del agua de la muestra es aceptable.

### 3.4. Programación

No se ha hecho ningún avance... Sera prioridad para las siguientes semanas el desarrollo de los primeros diagramas y aprendizajes frente a como crear la aplicación que se desea sincronizar con el robot.

3.5. Hablando de diagramas...

Se compartirán 3 Diagramas creados que explican la caja del robot, el funcionamiento del robot y como se implementara la tecnología a la caja de robot. Varios de estos diagramas fueron creados para taller y con estos se buscaban una mejor guía y acompañamiento del profesor ademas de una visión mas clara de nuestro proyecto.
CAJA NEGRA:


Figura 4: Caja negra Robot

DIAGRAMA TECNOLOGICO: ´


Figura 5: Diagrama tecnológico

6

DIAGRAMA DE FLUJO

]


Figura 6: Diagrama de flujo

En lo posible hacer zoom al documento para ver con claridad los diagramas.

FIN DEL INFORME

7

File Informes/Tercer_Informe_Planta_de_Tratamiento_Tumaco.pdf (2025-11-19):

# Tercer Informe Planta de Tratamiento Tumaco

Luis Cortes
Helen Hernandez
Sebastian Vanegas
Eddy Tocancipa
Jose Dario
Joseph Reyes

Noviembre 2025

## 1. Introducción

Durante la tercera semana de trabajo con el proyecto se realizaron avances en el tema de programación y manejo de sensores.
Se realizo la compra de los sensores expuestos en los anteriores informes y posterior programación ademas de ciertos apuntes frente a la comodidad y proceso de calibración.
Como adelanto, también se tienen listas las herramientas a usar para crear la aplicación referente a nuestro proyecto.

## 2. Calibración Sensores

Como previo inicio y a solicitud del profesor de taller se consiguieron datasheets, manuales y diagramas de conexión para los sensores, los cuales a la hora de usarlos por primera vez ayudaron en obtener los códigos de programación y procedimientos a seguir en la calibración, estos documentos se compartirán a continuación:

PH
1.Dame Click! (https://raaflahar.medium.com/ph-4502c-sensor-diymore-how-to-use-and-calibrate-using-arduino-uno-r3-3afc2b96631)
2. Dame Click! (https://cdn.awsli.com.br/969/969921/arquivos/ph-sensor-ph-4502c.pdf)
Conductividad
1. Dame Click! (https://randomnerdtutorials.com/esp32-tds-water-quality-sensor/)
2. Dame Click! (https://wiki.dfrobot.com/gravity__analog_tds_sensor___meter_for_arduino_sku__sen0244)
3. Dame Click! (https://babyelectronicsdxb.com/product/tds-meter-v1-0/)
Turbidez
1. Dame Click! (https://www.teachmemicro.com/esp32-turbidity-sensor/)
2. Dame Click! (https://manuals.plus/es/conrad/2734647-water-turbidity-test-sensor-for-arduino-manual)

1

NOTA: Los 3 sensores tienen parámetros genéricos para la industria por lo que no tienen datasheets dedicados en especifico a ellos, sus parámetros se encontraron adjuntos a las paginas de compra de sus desarrolladores.

### 2.1. Primeros Intentos:


Figura 1: Controlador PH

2


Figura 2: Buffers De PH y Sonda


Figura 3: Calibración Sonda

3


Figura 4: Pruebas con sensor de conductividad

Nuestro mayor problema al calibrar fue conseguir las soluciones ”Patrones”Necesarias para hacer el ajuste a los sensores. Se nos ocurrió presentarnos en la facultad de química donde solicitamos algunas de estas soluciones y el agua destilada necesaria para limpiar los sensores. Incluso aquí no pudimos conseguir una solución para el sensor de Turbidez por lo que esta requiere de una preparación casera a lo cual ya destinamos como tarea.
También el sitio de trabajo no fue muy cómodo ya que no prestaban los salones, aun así intentamos ser lo mas aseado posibles.

Conclusiones: Aprendimos gracias a manuales que el sensor de turbidez puede trabajar a 3.3V Incluso si su datasheet declara que 5v son requeridos, el único cambio es realizar un ajuste mas drástico en la programación. El sensor de PH es MUY delicado, y ajustar el potenciómetro a punta de uña fue un reto, también requerimos de un Convertidor de Nivel Lógico Bidireccional para bajar los Voltios de trabajo de 5 a 3.3, ya que no se pudo emparejar con el ESP32.
No tuvimos muchos problemas con el de conductividad, fue seguir la programación de manuales, aquí el reto fue escoger el sistema de unidades adecuados y cuadrar la formula.

4

## 3. Programación

### 3.1. Aplicación:

La aplicación se realizara en MIT APPINVENTOR Dame Click para ver la pagina! (https://ai2.appinventor.mit.edu/)
El ESP32 puede actuar como servidor web local al incluirse en su programación las librerías: WiFi.h y WebServer.h.
El código permite crear un servidor que responde en la dirección /datos con las lecturas de los sensores en formato JSON.
Ejemplo de dirección del servidor: http://192.168.0.105/datos
Ejemplo de respuesta JSON: ”ph”:7.1,”turbidez”:123,”tds”:550,çonductividad”:0.89

Ahora pa que esto? En MIT APPINVENTOR deja agregar un componente
WEB donde se empareja con el ESP32 y asi pasar los datos que este reciba.
Este proceso es programación con bloques:
Al presionar el botón “Actualizar datos”, se usa el bloque Web1.Get() para solicitar los datos al ESP32.
Cuando llega la respuesta se decodifica el texto JSON con Web.JsonTextDecode. Luego se actualizan las etiquetas con los valores de pH, turbidez, TDS y conductividad. (Estas etiquetas se crean en la interfaz del appinventor).
También puede añadirse un reloj (Clock) para actualizar los datos automáticamente cada cierto tiempo.
De resto es trabajo con la interfaz y crear Labels (Indicadores) para cada valor captado por el ESP32.

### 3.2. Base de datos:

Se pensó en una ”Nube”Donde se puedan almacenar las mediciones hechas por el usuario siguiendo el siguiente formato:
1. La aplicación poseerá un apartado ’Consulta de mediciones’.

### 2. En este apartado aparecen antiguas mediciones clasificadas con nombre y

fecha:
EJ: ”Medición Llave de Agua - 5/11/2025”

### 3. Al dar click en esta medición se mostraran los valores de PH, Conductividad

y Turbidez medidos en aquella fecha.

Como se realizara?: Por medio de Firebase. Se usara el servidor local creado por la ESP32 (URL) como base de datos, esta base de datos se guardaran con los respectivos parámetros en Firebase y creara una clave API. Esta clave API se enlaza con el componente FireBaseBD en APPINVENTOR para trasladar los datos guardados en la base.

5

## 4. Documentación

Se tiene una primera versión de un documento destinado al usuario para que aprenda de los valores que se trabajan con el robot, este documento se implementara en aplicación. Se subirá junto a este archivo al classroom.

## 5. Objetivos siguientes semanas:

Para las siguientes semanas (4, 5) del proyecto buscamos tener listo la calibración, esquema de conexión de los sensores así como el circuito y PCB, el prototipo de la aplicación que usaremos y bosquejos de la caja física donde se instalaran los sensores.

6

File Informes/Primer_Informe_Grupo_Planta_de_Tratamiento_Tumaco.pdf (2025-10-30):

# Primer Informe Equipo Planta de Tratamiento Tumaco

Joseph Reyes
Helen Hernandez
Jose Dario
Eddy Tocancipa
Sebastian Vanegas
Luis Cortes

October 2025

## 1. Introducción

Debido a la diferencia de horarios con 2 integrantes se instauro una reunión presencial el día martes.
Durante esa reunión se hablo a detalle sobre el cronograma y se definió las actividades de cada integrante para esta primer semana. Entre los primeros apuntes charlados durante la reunión, se llego a la aclaración de aplazar el apartado del diseño y esquema de la aplicación (Programación) A semanas posteriores como por ejemplo la semana 2 o 3, debido a que tenemos una falta de información en que materiales en especifico planeamos usar. Sin este conocimiento no tendríamos las bases para plantear al menos un esquema relacionado a la programación tanto de la aplicación como configuración de los componentes.

Siguiendo con otros apuntes hablados en la reunión, se definió que las primeras 4 semanas sean destinadas a todo el desarrollo conceptual, esquemático y planes dirigidos al robot, siendo las ultimas 3 semanas enfocadas al montaje, testeo y configuración del robot. Esto claro es la idea pero es posible que a medida que se avance tengamos que ir adelantando algunas partes de montaje o testeo de componentes.

1

## 2. Actividades

Se especificara en que nos dividimos cada integrante del equipo y algunos avances en estas actividades.

NOTA: Debido a carga académica, varias actividades no poseen mucha profundidad o información completa a fecha de hoy (Viernes). Esto ya que mucho del trabajo de investigación y socialización de este con el equipo se reservo para el fin de semana. Esto en plan de, para la siguiente reunión presencial (Martes) Hablar tanto de todos los progresos realizados durante la primera semana y cuadrar actividades grupales para la segunda semana.

### 2.1. Sensores:

Joseph Reyes - Sebastian Vanegas
Aquí se encarga de buscar que sensores se usaran en el robot, se consultaran precios, si son compatibles con micro-controladores y que parámetros medirán estos sensores. Parámetros que se buscan medir: Oxigeno, Presión, PH, Conductividad eléctrica, turbieza.
Oxigeno: Se encontraron sensores con precios altos (150k - 230k) que están en discusión si incluirlos al presupuesto.
Presión: No tenemos sensores en especifico.
PH: Se tiene el siguiente modelo (https://www.mercadolibre.com.co/para-controlador-de-medidor-de-ph-sonda-de-electrodo-de-ph/p/MCO2040588075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) (Se supone que al dar click en la palabra ”Modelo”debe mandar al enlace, no se si funcione jaja)
Conductividad eléctrica - Turbieza: Varios sensores encontrados comparten multiples parametros en donde la mayoria incluyen TDS (Solidos disueltos) por lo que con un sensor se podrian medir estos 2: Opcion1 (https://www.mercadolibre.com.co/modulo-de-deteccion-de-turbidez-en-agua-particulas-co/p/MCO2026025800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) Opcion2 (https://www.mercadolibre.com.co/sensor-de-conductividad-tds-calidad-agua-con-arduino-esp32/up/MCOU2408631068)


Figura 1: Ejemplo del sensor a usar

2

### 2.2. Controladores:

Eddy Tocancipa
Aquí se buscan los primeros pasos o instrucciones para controlar los sensores antes mencionados por medio de micro-controladores como lo serian el arduino o esp32, dependiendo de las necesidades.

Figura 2: Comparación del esquema de conexión y el circuito de pines.


(a) Esquema de PH.


(b) Circuito con pines orientado a IN-TERNET.

Se tienen los siguientes enlaces como material de ayuda en la consulta de como configurar estos sensores usando los micro-controladores:
Material Ayuda 1, (https://docs.cirkitdesigner.com/component/45f91b79-00fb-4eff-b3a2-2632bda1acbb/ph-sensor-with-module) Material Ayuda 2 (https://uelectronics.com/producto/sensor-de-ph-liquido/)
Aun se necesita conocer los comandos y múltiples configuraciones de estos sensores. Se planea discutir con los profesores de taller para obtener una guía en como poder estudiar estos y formas apropiadas de integrarlos en un mismo circuito. De momento se estudian conexiones simples, requerimientos y esquemas para conocer el funcionamiento del sensor.

### 2.3. Agua:

Luis Cortes
Tuvimos la conclusión de: ”Si, conocemos diferentes parámetros del agua, pero, ¿para que?”. Esta actividad se centra en estudiar el agua y como estos parámetros de medición nos ayudan a conocer el estado de agua y que tipo de contaminaciones tienen. Ademas de este informe, en los archivos de entrega se compartirá el informe de agua realizado por el compañero luis sobre las magnitudes de los diferentes parámetros y que conllevan.

3

### 2.4. Materiales:

Helen Hernandez - Jose Dario
En cuestión de materiales se tienen 2 ejes por investigar: 1: Chasis del robot. 2: Mecanismo de pegado.
1.Chasis del robot: Este debe ser impermeable y de buena resistencia al estar ubicado en ambientes húmedos y con constante contacto con el agua. Se usara una impresión 3D para crear el chasis usando PLA o ABS. Un factor clave en el chasis sera su recubrimiento, a lo cual se baraja la opción de usar teflón ya que ofrece buena protección ante líquidos y corrosión.
2.Mecanismo de pegado: El robot se ”pega.a la tubería, siendo estático y sirviendo como un punto de medición. Debido al material de la tubería que en su mayoría se compone de asbesto y cemento se complica mucho este punto. Aun no hay un enfoque claro pero se tienen 2 ideas a desarrollar:
*Idea 1 (Chupa): Similar a una chupa, el robot se pegaría a la tubería por medio de una ”succión.o presión.
*Idea 2 (Ancla): Por medio de un mecanismo de peso, el robot en un momento dado se .anclaría.a la tubería o por debajo del agua.
Ambas ideas requieren una mayor profundización que se espera aclarar con el grupo durante el desarrollo al completo de las actividades durante el fin de semana.

FIN DEL INFORME

4

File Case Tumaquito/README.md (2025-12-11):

# BOCETO Y MODELADO:

Aqui tendras el boceto hecho en tinkercard que se uso para el modelado

Ademas podras encontrar el propio modelado 3D hecho en la aplicación de laminado ligada al anycubic slicer (Impresora)

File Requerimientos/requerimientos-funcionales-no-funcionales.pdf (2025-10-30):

### LANG: ES

## FLUJO DE DISEÑO

Presentado por Johnny Cubides

reveal.js | http://localhost:8000/
1 of 15 | 10/25/25, 8:30 AM

### DESCRIPCIÓN

Se presenta el flujo de diseño para la creación de prototipos con herramientas opensource tanto de hardware como de soware.

Requerimientos funcionales / no funcionales; Diagrama de flujo; Diagrama de Caja Negra; Diagrama tecnológico; Nueva iteración del proceso; Hardware Case; Contenedor; Software; Prototipo Finalizado; Inicio de Prototipo; Proceso documental; Cumple con los requerimientos

## FASES DEL FLUJO DE DISEÑO

### REQUERIMIENTOS FUNCIONALES Y NO FUNCIONALES

Objetivos a alcanzar en función de la situación abordada en contexto. Producto mínimo viable
The business model canvas

SITUACIÓN PROBLEMA


SITUACIÓN PROBLEMA

Durante la pandemia de COVID-19 en 2019, la creciente demanda de respiradores en las unidades de cuidados intensivos expuso una crítica falta de disponibilidad de estos equipos esenciales en los hospitales. El aumento exponencial de pacientes con complicaciones respiratorias severas sobrepasó rápidamente la capacidad instalada, generando una crisis en la atención médica. Esta escasez no solo limitó la capacidad de los hospitales para tratar a los pacientes más graves, sino que también obligó al personal médico a tomar decisiones éticamente complejas sobre la asignación de recursos, impactando tanto la calidad del cuidado como las tasas de supervivencia.

PROTOTIPO

Para hacer frente a la escasez de respiradores, se creará un dispositivo utilizando herramientas de prototipado rápido como cortadoras láser, impresoras 3D y plataformas como Arduino. Este respirador será diseñado para ser de bajo costo y fácil de producir rápidamente, adaptándose a las necesidades de los hospitales. La fabricación de piezas precisas se realizará mediante cortadoras láser, mientras que las impresoras 3D se utilizarán para crear componentes personalizados. El control de los sistemas electrónicos será gestionado a través de Arduino, permitiendo la creación de una alternativa viable para incrementar la disponibilidad de respiradores en momentos de alta demanda.

PROTOTIPO


REQUERIMIENTOS FUNCIONALES

1. Monitoreo de presión y flujo de aire: El respirador debe ser capaz de medir y controlar la presión y el flujo de aire para asegurar que se administren niveles adecuados de oxígeno al paciente, adaptándose a sus necesidades respiratorias.
2. Control de parámetros ajustables: Debe permitir la configuración de parámetros clave como la frecuencia respiratoria, volumen tidal y la relación inspiración/ espiración, asegurando la personalización según las condiciones del paciente.
3. Alarma de seguridad: El respirador debe contar con un sistema de alarmas que avise al personal médico en caso de mal funcionamiento, como fallos en la presión o flujo de aire, o si los parámetros caen fuera de los rangos seguros.

REQUERIMIENTOS NO FUNCIONALES

1. Seguridad: El respirador debe contar con sistemas de monitoreo y alarmas que garanticen su funcionamiento dentro de los parámetros seguros, alertando al personal médico ante cualquier irregularidad que pueda comprometer la salud del paciente.
2. Fiabilidad: El respirador debe ser altamente confiable, con un diseño robusto que minimice los riesgos de fallos mecánicos o electrónicos durante su uso prolongado, asegurando su correcto funcionamiento en todo momento.
3. Durabilidad: El respirador debe estar fabricado con materiales resistentes que aseguren su funcionamiento a largo plazo, incluso en condiciones de uso intenso, manteniendo su eficiencia y resistencia ante el desgaste.

EVALUACIÓN DE REQUERIMIENTOS

El desarrollo de respiradores mediante tecnologías de prototipado rápido, como impresoras 3D, cortadoras láser y plataformas como Arduino, enfrenta importantes dificultades para cumplir con los estrictos estándares y normas médicas internacionales que aseguran la seguridad y eficacia de los dispositivos médicos. Normas como las de la FDA o ISO 13485 exigen rigurosos procesos de certificación, pruebas exhaustivas de calidad y controles estrictos sobre los materiales y la fabricación, aspectos que son difíciles de alcanzar en estos prototipos. La falta de experiencia en producción a gran escala, el control de calidad continuo y la trazabilidad de los componentes hacen que estos dispositivos no cumplan con los requisitos exigidos para garantizar su fiabilidad y seguridad en un entorno clínico profesional.

CANVAS

Revenue Streams

Channels

Key Partners | Key Activities | Value Propositions | Customer Relationships | Customer Segments

Key Resources

Cost Structure

www.businessmodelgeneration.com

The Business Model Canvas | On: Iteration:
Designed for: | Designed by:
Day | Mongith | Year

No.

This work is licensed under the Creative Commons Attribution-Share Alike 3.0 Unported License. To view a copy of this license, visit http://creativecommons.org/ licenses/ by-sa/ 3.0/ or send a letter to Creative Commons, 171 Second Street, Suite 300, San Francisco, California, 94105, USA.

* Estudiantes de colegios distritales (públicos y privados)
de educación secundaria que no cuentan con herramientas de desarrollo tecnológico (Hardware/Software) para el desarrollo de prototipos rápidos
para los retor o proyectos propuestos en el aula de clase

* Profesores de educación secundaria que requiere una herramienta tecnológica que les permita junto a una metodología desarrollar talleres, guías, para adquirir algún conocimiento de su área usando.

Kit de programación de
hardware educativo que no requiere infraestructura en el lugar más allá de un celular con Android 4.0+

* Actividades demostrativas en colegios de experiencias de aprendizaje donde el estudiante podrá probar el uso de la herramienta con su profesor de clase.

* Pagina web que contiene tutoriales y prácticas o ejercicios que se pueden hacer con ésta herramienta.

* Participación de eventos tecnológicos con prototipos realizados con ésta herramienta (Scratch Day Arduino Day)

* Suministro de kit de desarrollo

* Suminitro de guias metodológicas

* Capacitaciones sobre uso de herramientas vía onlie

* Personal capacitado en el desarrollo de metodologías educativas activas

* Personal diseñador y programador de hardware y software

* Personal de diseño industrial

* Personal en estrategia de formulación de proyectos con conocimientos en licitaciones con el distrito

* Equipo de computo y de prototipado

* Diseño y desarrollo de hardware educativo

* Diseño y desarrollo de aplicaciones para la programación de hardware

* Venta de kits a colegios distritales públicos y privados

* Empresas chinas de creación de PCBs

* Proveedores de material electrónico de tipo educativo para crear kits

* Empresas de creación de manufactura y producción (Empaquetado)

* Creación de material tecnológico en el exterior, como lo son las PCB en china. * Importación de componentes electrónicos (digikey, mouser)
* Montaje de componentes superficiales
* Creación de kist por compra de componentes a proveedores
* Montaje de sitio Web
* Montaje para la aplicación de Android en la AppStore

* Aplicación de cursos de metodologías disrruptivas en educación orientado a profesores

* Aplicación de cursos de programación para estudiantes de colegio

Speaker notes

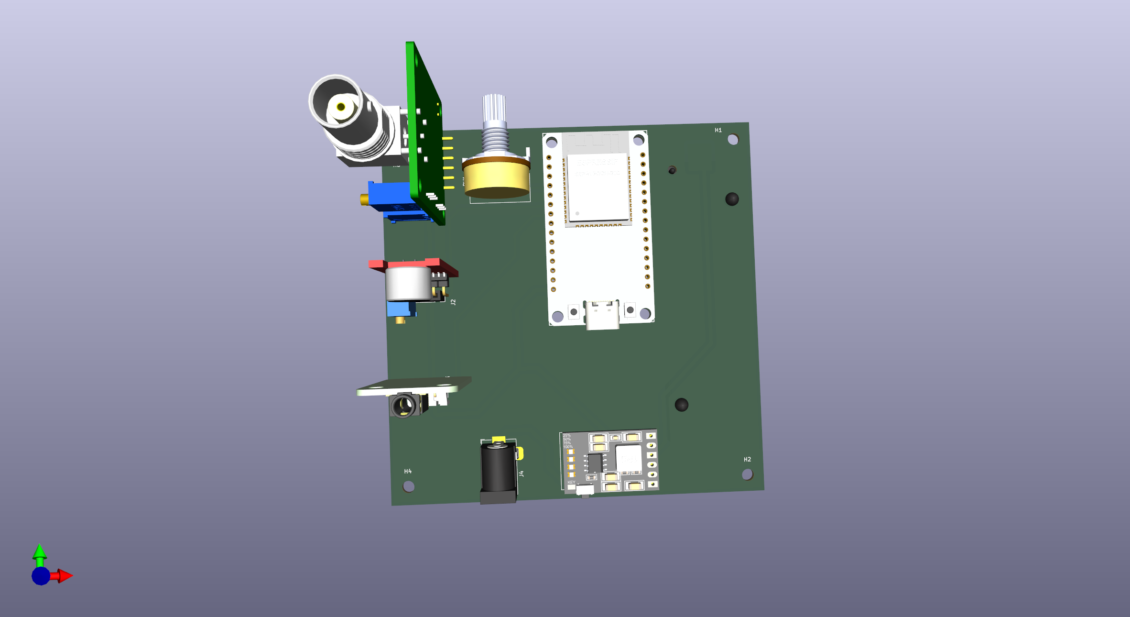
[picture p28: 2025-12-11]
PCB Tumaquito/Imagenes 3D/Capa exterior.png

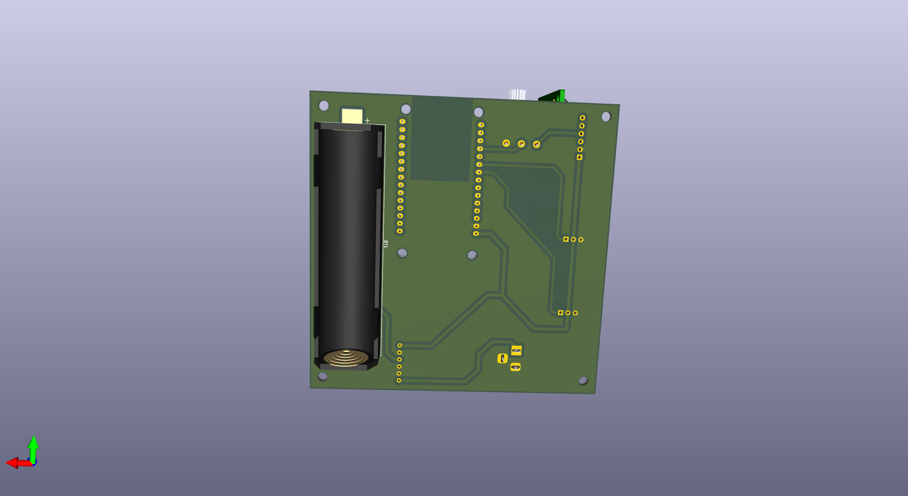
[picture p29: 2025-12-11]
PCB Tumaquito/Imagenes 3D/Capa inferior.png

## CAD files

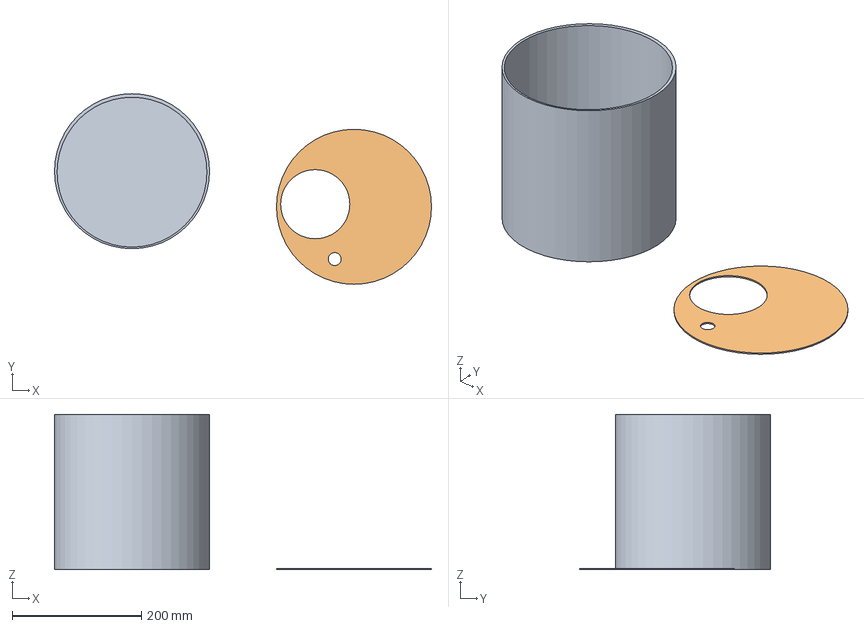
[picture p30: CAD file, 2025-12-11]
Case Tumaquito/3D Tumaquito.3mf
583.7 x 295.1 x 240.5 mm
Brilliant Uusam (6).stl
cajita _D (3).stl

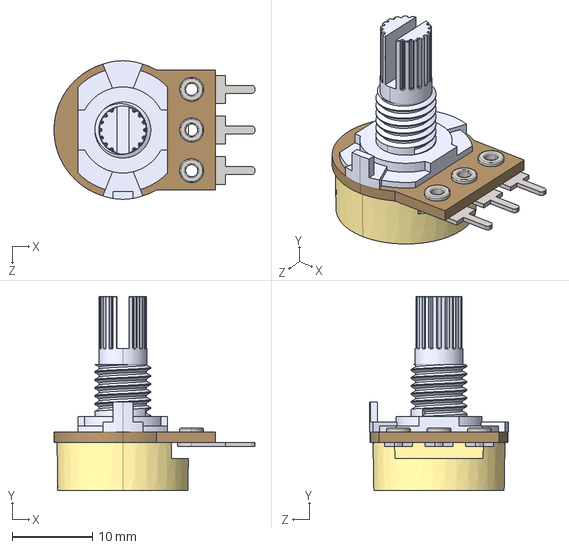
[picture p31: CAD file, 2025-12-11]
PCB Tumaquito/Librerias/potentiometer.STEP
25.1 x 24.2 x 17.3 mm

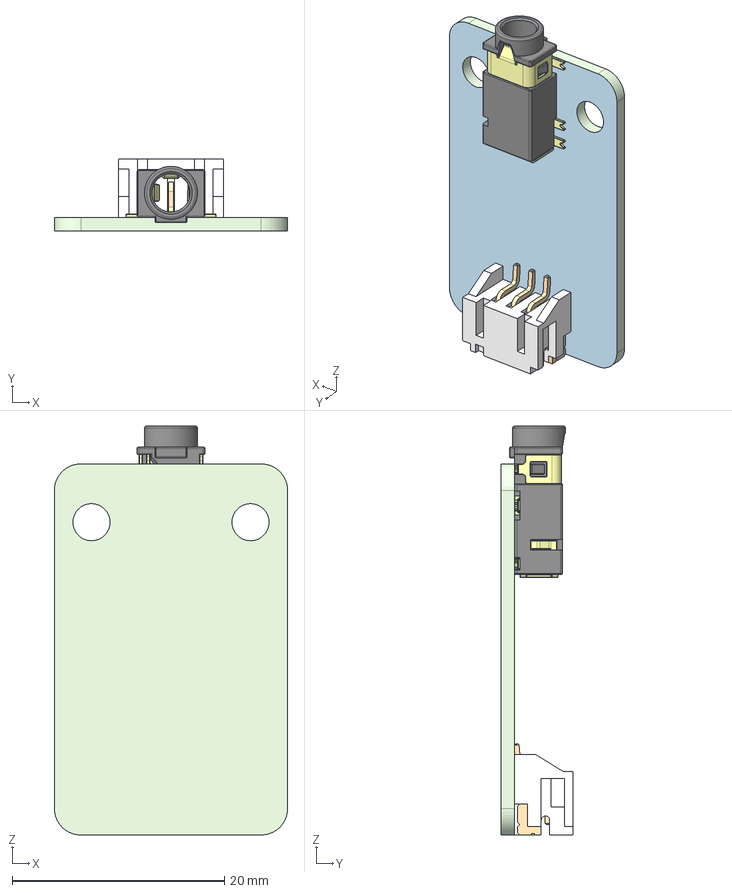
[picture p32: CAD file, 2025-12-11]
PCB Tumaquito/Librerias/step/dfrobot-gravity-analog-emg-sensor-by-oymotion-sen0240-1.snapshot.2/amplifier_emg.step
22.0 x 6.80 x 38.6 mm
006^PJ311D_WOPos
007^PJ311D_WOPos
002^PJ311D_WOPos
003^PJ311D_WOPos
001^PJ311D_WOPos
004^PJ311D_WOPos
005^PJ311D_WOPos
JST-S3B-PH-SM4-TB x 3

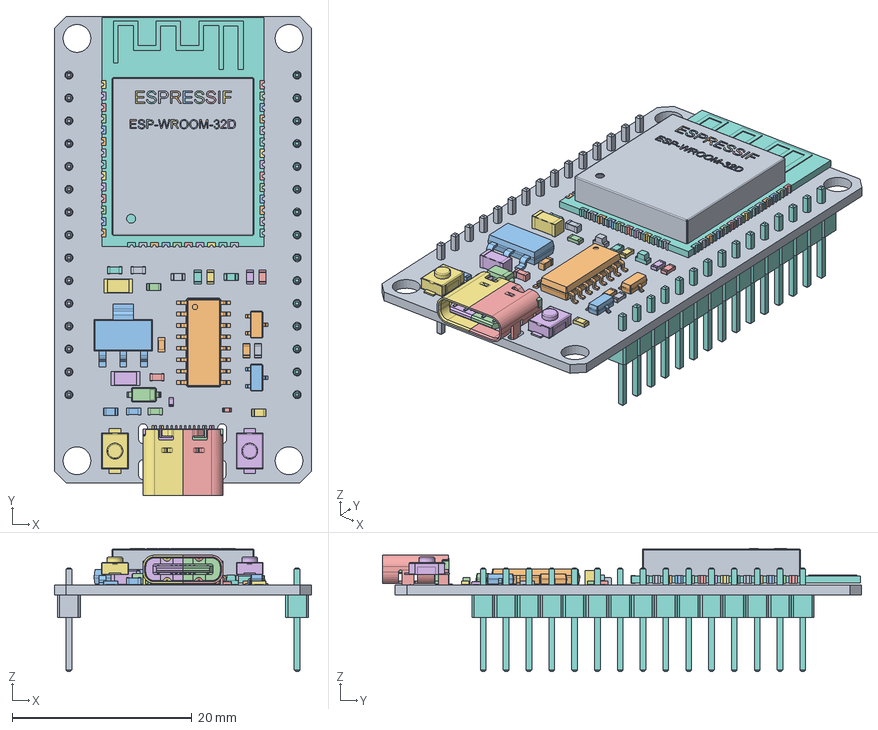
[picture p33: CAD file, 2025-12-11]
PCB Tumaquito/Librerias/step/esp32-wroom-32d-devkit-ch340-usb-c-1.snapshot.10/esp32_wroom_32D_kitV1_wph.FCStd
28.6 x 53.3 x 13.7 mm
PCB
SOIC_16_39x99mm_P127mm
SOT_223
USB_C_Receptacle_16P_TopMnt_Horizontal_GCT_USB4105-xx-A
USB_C_Receptacle_16P_TopMnt_Horizontal_GCT_USB4105-xx-A001
USB_C_Receptacle_16P_TopMnt_Horizontal_GCT_USB4105-xx-A002
USB_C_Receptacle_16P_TopMnt_Horizontal_GCT_USB4105-xx-A003
USB_C_Receptacle_16P_TopMnt_Horizontal_GCT_USB4105-xx-A004
USB_C_Receptacle_16P_TopMnt_Horizontal_GCT_USB4105-xx-A005
USB_C_Receptacle_16P_TopMnt_Horizontal_GCT_USB4105-xx-A006
USB_C_Receptacle_16P_TopMnt_Horizontal_GCT_USB4105-xx-A007
USB_C_Receptacle_16P_TopMnt_Horizontal_GCT_USB4105-xx-A008
USB_C_Receptacle_16P_TopMnt_Horizontal_GCT_USB4105-xx-A009
USB_C_Receptacle_16P_TopMnt_Horizontal_GCT_USB4105-xx-A010
USB_C_Receptacle_16P_TopMnt_Horizontal_GCT_USB4105-xx-A011
USB_C_Receptacle_16P_TopMnt_Horizontal_GCT_USB4105-xx-A012
USB_C_Receptacle_16P_TopMnt_Horizontal_GCT_USB4105-xx-A013
USB_C_Receptacle_16P_TopMnt_Horizontal_GCT_USB4105-xx-A014
USB_C_Receptacle_16P_TopMnt_Horizontal_GCT_USB4105-xx-A015
USB_C_Receptacle_16P_TopMnt_Horizontal_GCT_USB4105-xx-A016
USB_C_Receptacle_16P_TopMnt_Horizontal_GCT_USB4105-xx-A017
USB_C_Receptacle_16P_TopMnt_Horizontal_GCT_USB4105-xx-A018
USB_C_Receptacle_16P_TopMnt_Horizontal_GCT_USB4105-xx-A019
USB_C_Receptacle_16P_TopMnt_Horizontal_GCT_USB4105-xx-A020
USB_C_Receptacle_16P_TopMnt_Horizontal_GCT_USB4105-xx-A021
USB_C_Receptacle_16P_TopMnt_Horizontal_GCT_USB4105-xx-A022
USB_C_Receptacle_16P_TopMnt_Horizontal_GCT_USB4105-xx-A023
USB_C_Receptacle_16P_TopMnt_Horizontal_GCT_USB4105-xx-A024
USB_C_Receptacle_16P_TopMnt_Horizontal_GCT_USB4105-xx-A025
USB_C_Receptacle_16P_TopMnt_Horizontal_GCT_USB4105-xx-A026
USB_C_Receptacle_16P_TopMnt_Horizontal_GCT_USB4105-xx-A027
USB_C_Receptacle_16P_TopMnt_Horizontal_GCT_USB4105-xx-A028
USB_C_Receptacle_16P_TopMnt_Horizontal_GCT_USB4105-xx-A029
USB_C_Receptacle_16P_TopMnt_Horizontal_GCT_USB4105-xx-A030
USB_C_Receptacle_16P_TopMnt_Horizontal_GCT_USB4105-xx-A031
USB_C_Receptacle_16P_TopMnt_Horizontal_GCT_USB4105-xx-A032
USB_C_Receptacle_16P_TopMnt_Horizontal_GCT_USB4105-xx-A033
USB_C_Receptacle_16P_TopMnt_Horizontal_GCT_USB4105-xx-A034
USB_C_Receptacle_16P_TopMnt_Horizontal_GCT_USB4105-xx-A035
LED_0603_D2
LED_0603_PWR
SOT_23_1
SOT_23_002
D_SOD_123
R_0603_
R_0603_001
R_0603_002
R_0603_003
R_0603_004
R_0603_005
R_0603_006
R_0603_007
R_0402_001
R_0402_002
R_0603_008
C_0603_
C_0603_001
C_0603_002
C_0603_003
C_0603_004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

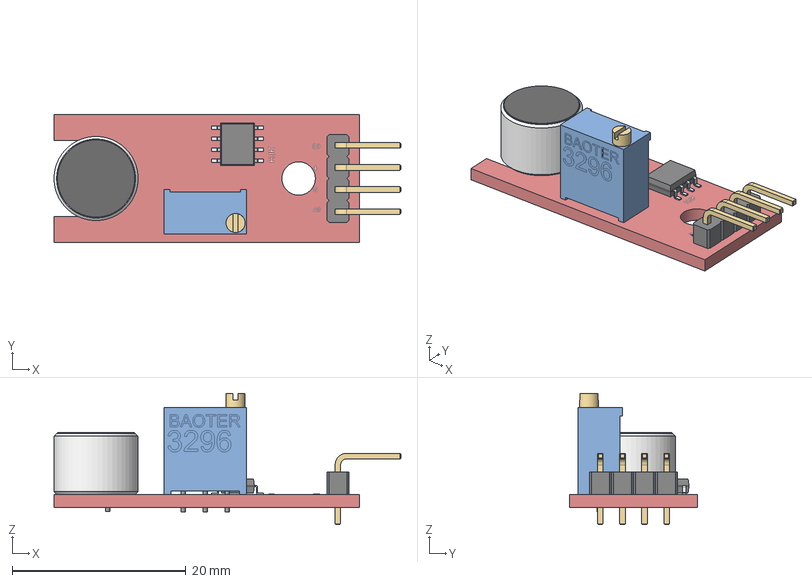
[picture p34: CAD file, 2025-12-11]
PCB Tumaquito/Librerias/step/ky-037-microphone-module-1.snapshot.3/KY-037_Microphpone_Module.stp
40.0 x 14.8 x 15.1 mm
HJX_Mike_PCB
Mike_housing
Mike_cap
Mike_terminal x 2
SOIC-8
Bao_3296_Body
Bao_3296_Adj_Trim
Bao_3296_Terminal x 3
1X4_Pin_Holder
90_Pin_M x 4

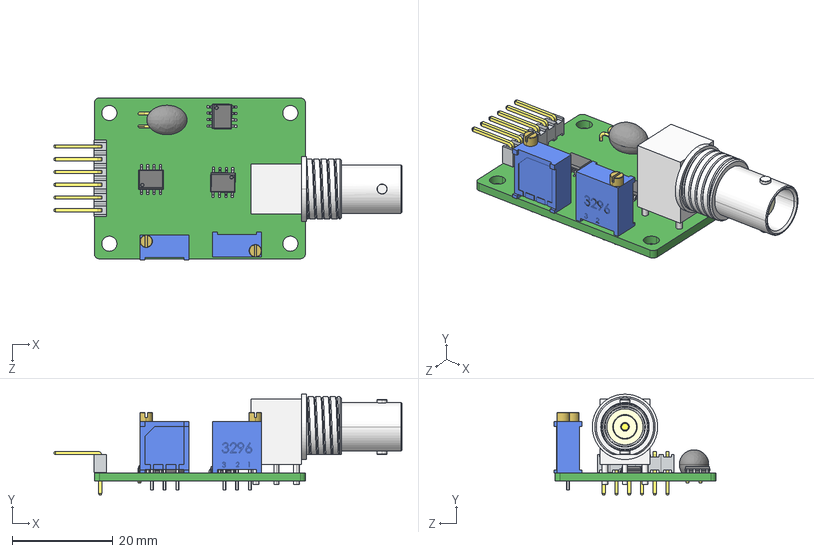
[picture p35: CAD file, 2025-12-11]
PCB Tumaquito/Librerias/step/ph-4502c-1.snapshot.5/PH-4502C.STEP
69.2 x 20.0 x 32.3 mm
Board_ph
BNC_90
Trimpot multivoltas_Valor predeterminado x 2
pin_header_6
S08.stp x 3
ptc

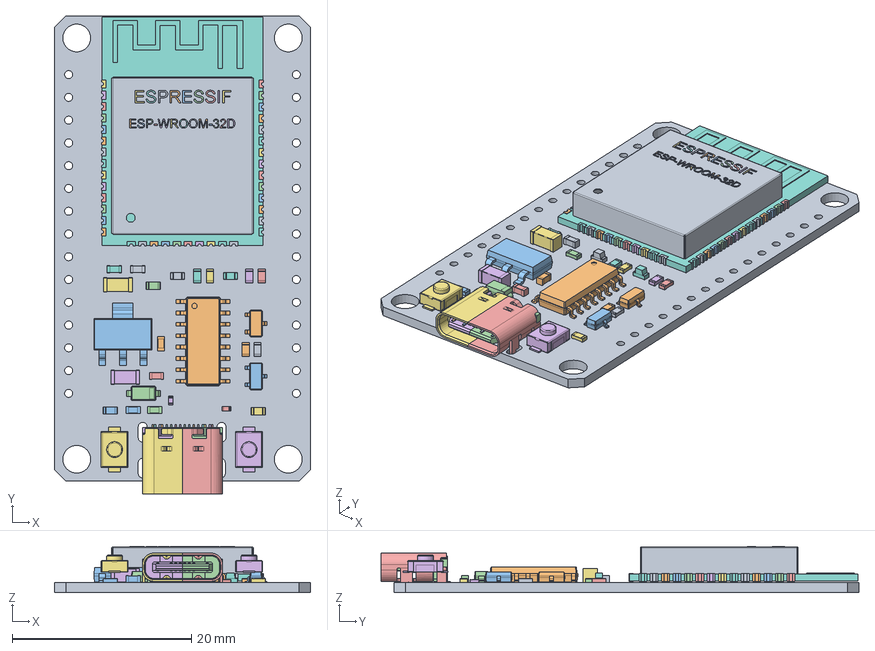
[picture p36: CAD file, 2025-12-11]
PCB Tumaquito/Librerias/step/esp32-wroom-32d-devkit-ch340-usb-c-1.snapshot.10/esp32_wroom_32D_kitV1.FCStd
28.6 x 53.3 x 5.15 mm
PCB
SOIC_16_39x99mm_P127mm
SOT_223
USB_C_Receptacle_16P_TopMnt_Horizontal_GCT_USB4105-xx-A
USB_C_Receptacle_16P_TopMnt_Horizontal_GCT_USB4105-xx-A001
USB_C_Receptacle_16P_TopMnt_Horizontal_GCT_USB4105-xx-A002
USB_C_Receptacle_16P_TopMnt_Horizontal_GCT_USB4105-xx-A003
USB_C_Receptacle_16P_TopMnt_Horizontal_GCT_USB4105-xx-A004
USB_C_Receptacle_16P_TopMnt_Horizontal_GCT_USB4105-xx-A005
USB_C_Receptacle_16P_TopMnt_Horizontal_GCT_USB4105-xx-A006
USB_C_Receptacle_16P_TopMnt_Horizontal_GCT_USB4105-xx-A007
USB_C_Receptacle_16P_TopMnt_Horizontal_GCT_USB4105-xx-A008
USB_C_Receptacle_16P_TopMnt_Horizontal_GCT_USB4105-xx-A009
USB_C_Receptacle_16P_TopMnt_Horizontal_GCT_USB4105-xx-A010
USB_C_Receptacle_16P_TopMnt_Horizontal_GCT_USB4105-xx-A011
USB_C_Receptacle_16P_TopMnt_Horizontal_GCT_USB4105-xx-A012
USB_C_Receptacle_16P_TopMnt_Horizontal_GCT_USB4105-xx-A013
USB_C_Receptacle_16P_TopMnt_Horizontal_GCT_USB4105-xx-A014
USB_C_Receptacle_16P_TopMnt_Horizontal_GCT_USB4105-xx-A015
USB_C_Receptacle_16P_TopMnt_Horizontal_GCT_USB4105-xx-A016
USB_C_Receptacle_16P_TopMnt_Horizontal_GCT_USB4105-xx-A017
USB_C_Receptacle_16P_TopMnt_Horizontal_GCT_USB4105-xx-A018
USB_C_Receptacle_16P_TopMnt_Horizontal_GCT_USB4105-xx-A019
USB_C_Receptacle_16P_TopMnt_Horizontal_GCT_USB4105-xx-A020
USB_C_Receptacle_16P_TopMnt_Horizontal_GCT_USB4105-xx-A021
USB_C_Receptacle_16P_TopMnt_Horizontal_GCT_USB4105-xx-A022
USB_C_Receptacle_16P_TopMnt_Horizontal_GCT_USB4105-xx-A023
USB_C_Receptacle_16P_TopMnt_Horizontal_GCT_USB4105-xx-A024
USB_C_Receptacle_16P_TopMnt_Horizontal_GCT_USB4105-xx-A025
USB_C_Receptacle_16P_TopMnt_Horizontal_GCT_USB4105-xx-A026
USB_C_Receptacle_16P_TopMnt_Horizontal_GCT_USB4105-xx-A027
USB_C_Receptacle_16P_TopMnt_Horizontal_GCT_USB4105-xx-A028
USB_C_Receptacle_16P_TopMnt_Horizontal_GCT_USB4105-xx-A029
USB_C_Receptacle_16P_TopMnt_Horizontal_GCT_USB4105-xx-A030
USB_C_Receptacle_16P_TopMnt_Horizontal_GCT_USB4105-xx-A031
USB_C_Receptacle_16P_TopMnt_Horizontal_GCT_USB4105-xx-A032
USB_C_Receptacle_16P_TopMnt_Horizontal_GCT_USB4105-xx-A033
USB_C_Receptacle_16P_TopMnt_Horizontal_GCT_USB4105-xx-A034
USB_C_Receptacle_16P_TopMnt_Horizontal_GCT_USB4105-xx-A035
LED_0603_D2
LED_0603_PWR
SOT_23_1
SOT_23_002
D_SOD_123
R_0603_
R_0603_001
R_0603_002
R_0603_003
R_0603_004
R_0603_005
R_0603_006
R_0603_007
R_0402_001
R_0402_002
R_0603_008
C_0603_
C_0603_001
C_0603_002
C_0603_003
C_0603_004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

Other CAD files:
PCB Tumaquito/Librerias/step/ph-4502c-1.snapshot.5/PH-4502C.DXF

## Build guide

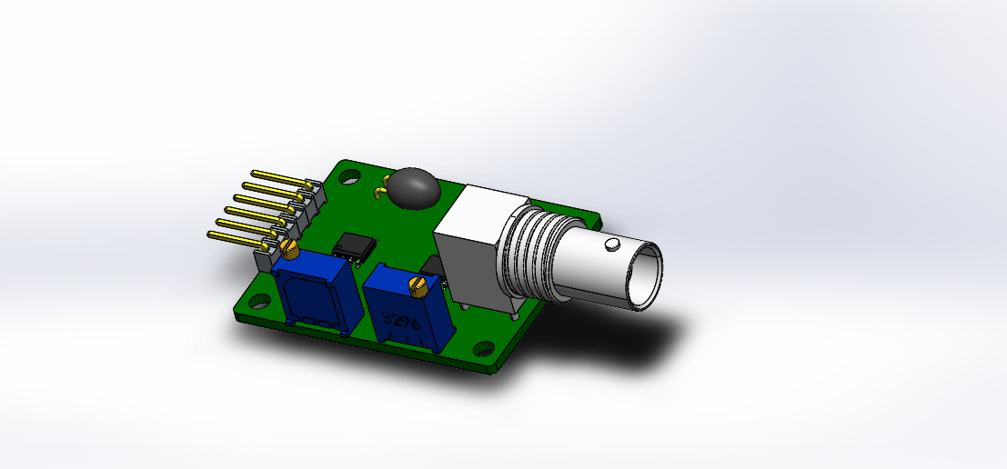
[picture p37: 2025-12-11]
PCB Tumaquito/Librerias/step/ph-4502c-1.snapshot.5/PH-4502C-.JPG

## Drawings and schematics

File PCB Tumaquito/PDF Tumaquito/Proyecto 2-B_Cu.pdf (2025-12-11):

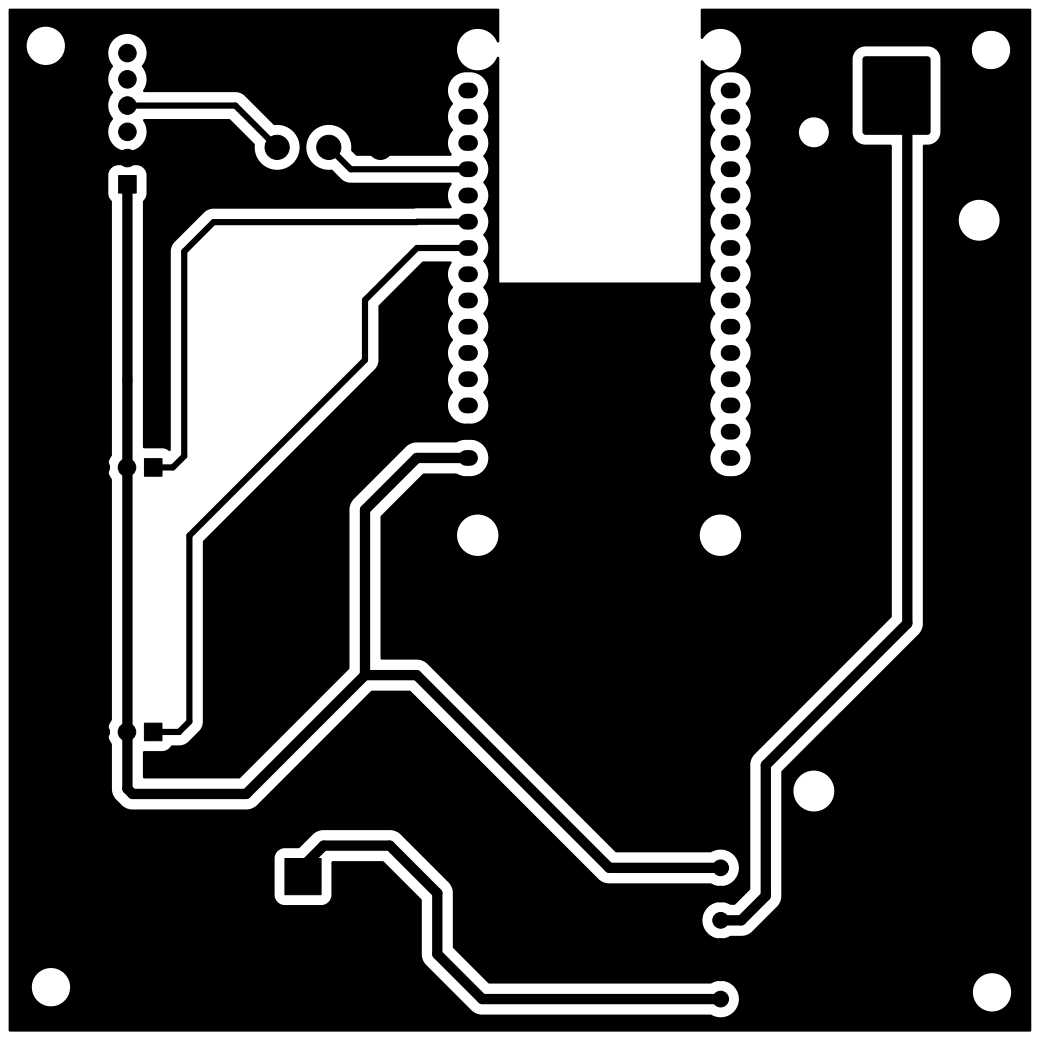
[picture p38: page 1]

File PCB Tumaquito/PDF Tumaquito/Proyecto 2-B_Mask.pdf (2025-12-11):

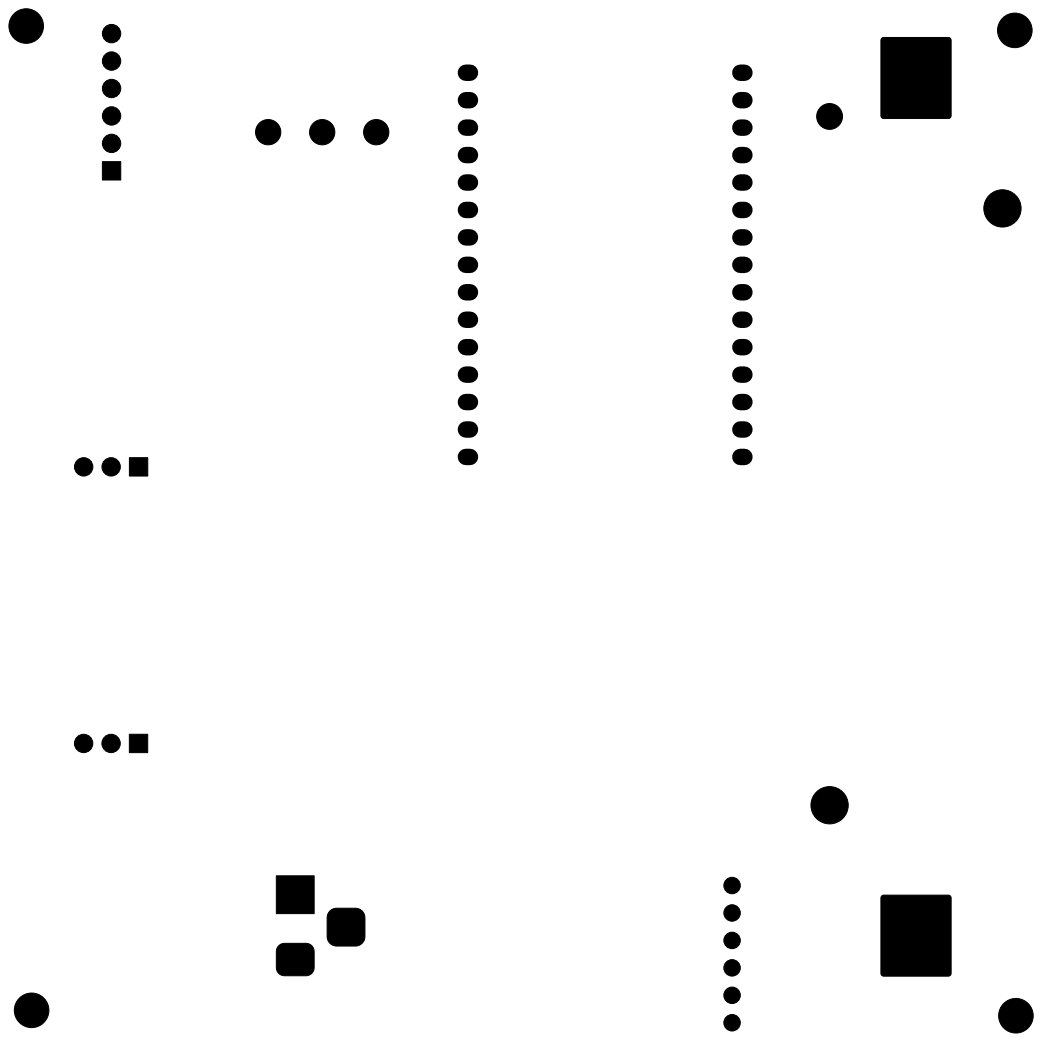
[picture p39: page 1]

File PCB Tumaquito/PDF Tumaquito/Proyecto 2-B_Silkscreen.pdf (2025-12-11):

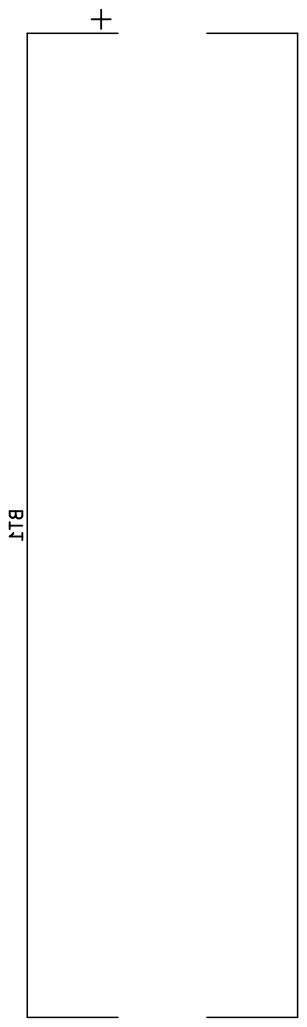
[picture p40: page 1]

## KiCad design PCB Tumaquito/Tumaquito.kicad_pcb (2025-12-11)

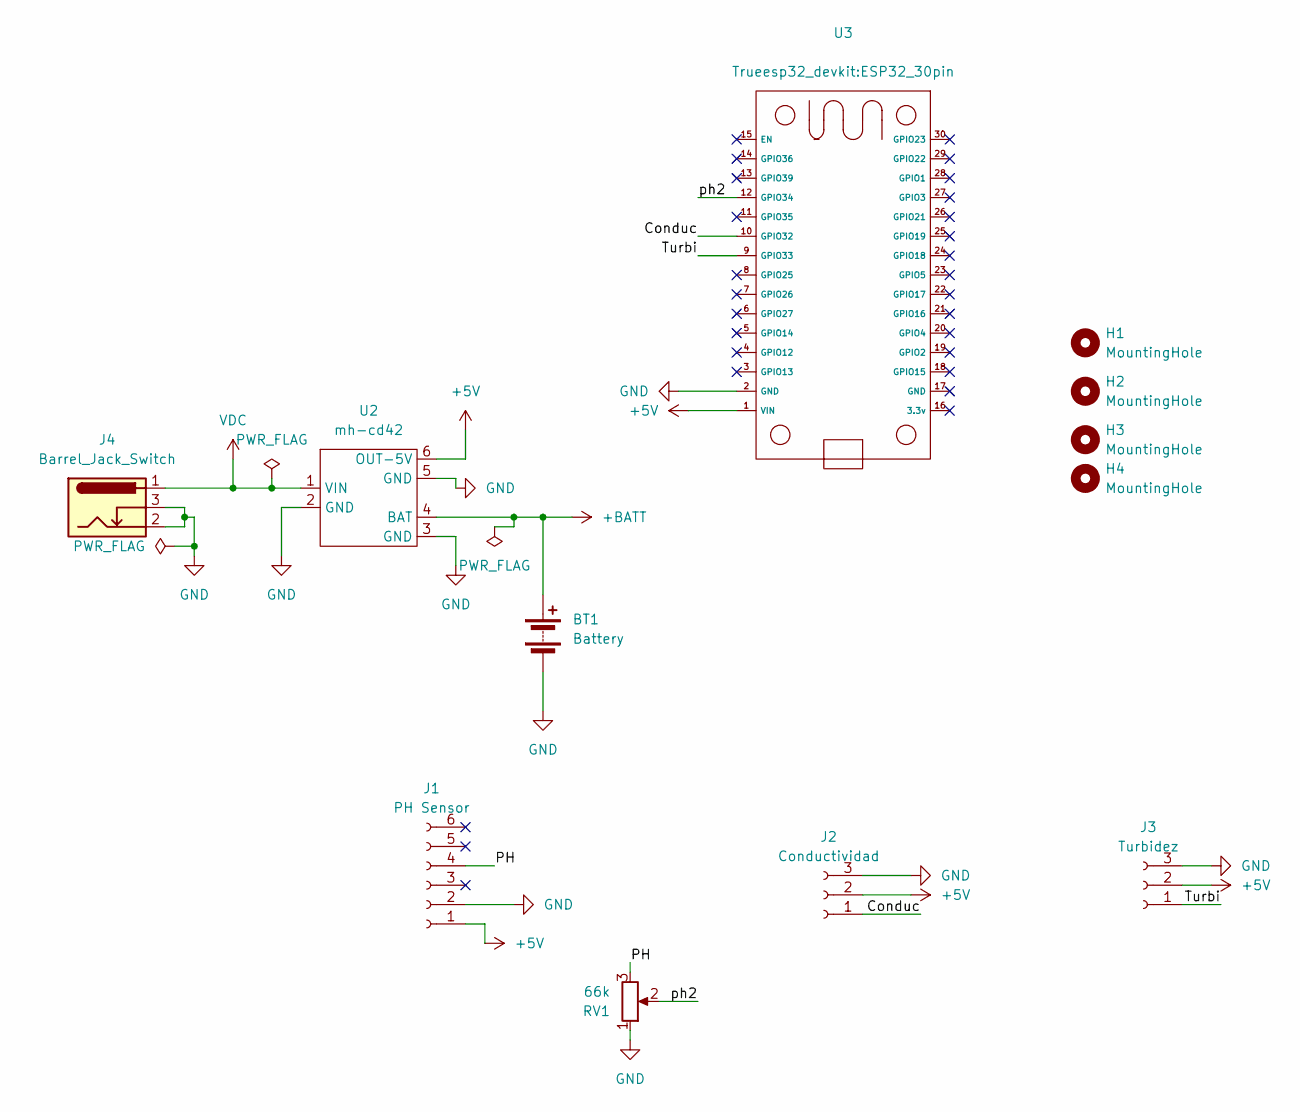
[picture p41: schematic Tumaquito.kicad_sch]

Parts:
BT1: Battery; BatteryHolder_Keystone_1042_1x18650
H1, H2, H3, H4: MountingHole; MountingHole_3.2mm_M3
J1: PH Sensor; PinSocket_1x06_P2.54mm_Vertical
J2: Conductividad; PinSocket_1x03_P2.54mm_Vertical
J3: Turbidez; PinSocket_1x03_P2.54mm_Vertical
J4: Barrel_Jack_Switch; BarrelJack_Horizontal
RV1: 66k; Potentiometer_Piher_T-16H_Single_Horizontal
U2: mh-cd42
U3: ESP32_30pin

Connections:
+5V: J1.1, J2.2, J3.2, U2.6 (OUT-5V), U3.1 (VIN)
+BATT: BT1.1 (+), U2.4 (BAT)
/Conduc: J2.1, U3.10 (GPIO32)
/PH: J1.4, RV1.3
/Turbi: J3.1, U3.9 (GPIO33)
/ph2: RV1.2, U3.12 (GPIO34)
GND: BT1.2 (-), J1.2, J2.3, J3.3, J4.2, J4.3, RV1.1, U2.2 (GND), U2.3 (GND), U2.5 (GND), U3.2 (GND)
VDC: J4.1, U2.1 (VIN)

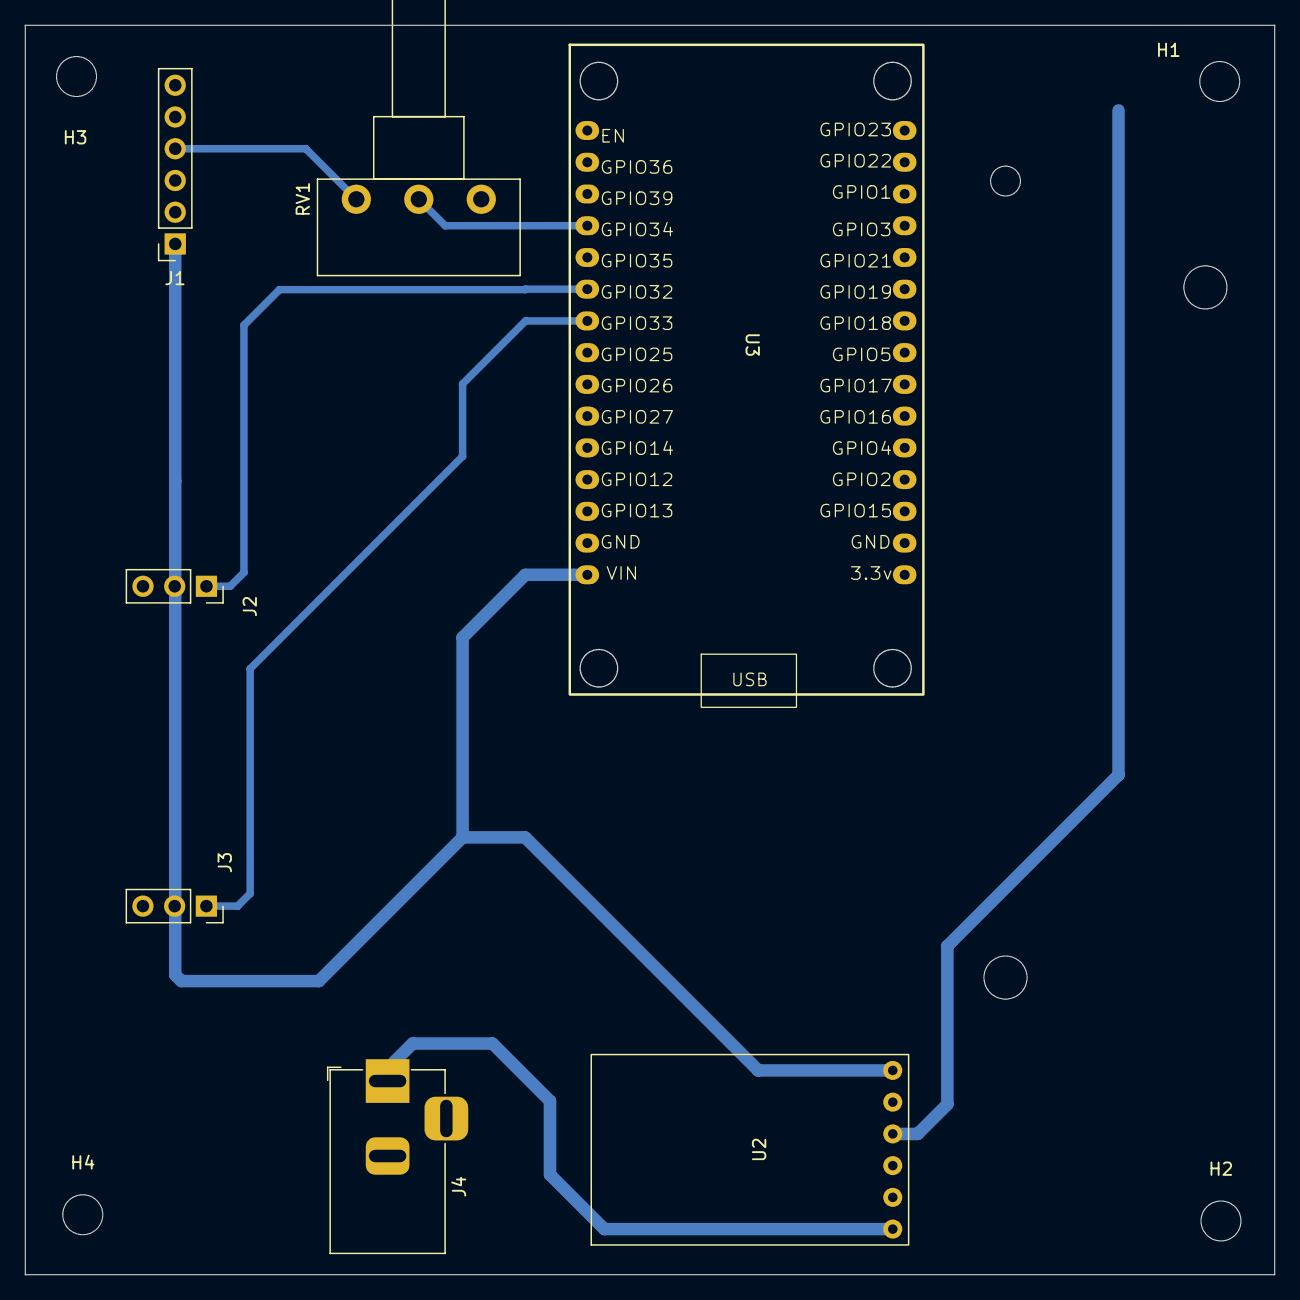
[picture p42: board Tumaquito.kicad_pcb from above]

Board: 2 copper layers, 100.0 x 100.0 mm, 12 parts (1 on the bottom side), 8 nets.

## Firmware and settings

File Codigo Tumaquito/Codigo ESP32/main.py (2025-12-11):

import archivo
import socket

addr = socket.getaddrinfo("0.0.0.0", 80)[0][-1]
s = socket.socket()
s.bind(addr)
s.listen(1)
print("Servidor listo en puerto 80")

led.on()

while True:
    cl, addr = s.accept()
    print("Cliente:", addr)

    peticion = cl.recv(1024).decode()
    print("Petición:\n", peticion)

   
    if "GET /archivo.json" in peticion:
        with open("archivo.json") as f:
            contenido = f.read()

        cl.send("HTTP/1.1 200 OK\r\n")
        cl.send("Content-Type: application/json\r\n")
        cl.send("Connection: close\r\n\r\n")   
        cl.send(contenido)

    else:
        cl.send("HTTP/1.1 404 Not Found\r\n")
        cl.send("Content-Type: text/plain\r\n")
        cl.send("Connection: close\r\n\r\n")
        cl.send("Archivo no encontrado")

    cl.close()
    led.off()

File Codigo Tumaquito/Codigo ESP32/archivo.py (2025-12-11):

from funcionC import conductividad
import time
from machine import ADC, Pin
import json

# Listas para almacenar acumulados
datos = [0, 0, 0]  # [cond, ph, turb]

# Configurar ADC una sola vez
sensor_turb = ADC(Pin(34))
sensor_turb.atten(ADC.ATTN_11DB)

sensor_ph = ADC(Pin(32))
sensor_ph.atten(ADC.ATTN_11DB)

# --- Proceso ---
for i in range(50):
    for _ in range(3):

        # conductividad (función externa)
        cond = conductividad()

        # turbidez
        turb = sensor_turb.read()

        # ph
        ph = sensor_ph.read()

        # Acumular cada sensor
        datos[0] += cond
        datos[1] += ph
        datos[2] += turb
        print("cond= ",cond," ph= ",ph," tubr= ",turb)
        time.sleep(0.2)

# Promedio de cada sensor
for i in range(3):
    datos[i] /= 50
 

arch={
    "cond":datos[0],
    "ph":datos[1],
    "turb":datos[2]}
print("Promedios:", arch)

#json
archivo="archivo.json"
with open(archivo,"w") as file:
    json.dump(arch, file)

    
    

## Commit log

2025-11-26 Create PCB Tumaquito-20251126T024410Z-1-001.zip
2025-12-11 PCB Update
    [KY-037_Microphpone_Module.stp, PH-4502C.DXF, PH-4502C.STEP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]
2025-12-11 Adding the 2 last folders
    [3D Tumaquito.3mf, KY-037_Microphpone_Module.stp, PH-4502C.DXF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]
